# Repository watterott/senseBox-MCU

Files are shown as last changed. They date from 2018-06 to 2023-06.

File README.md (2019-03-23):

# senseBox MCU
senseBox MCU is a Microchip SAMD21 based open-source board for sensors.

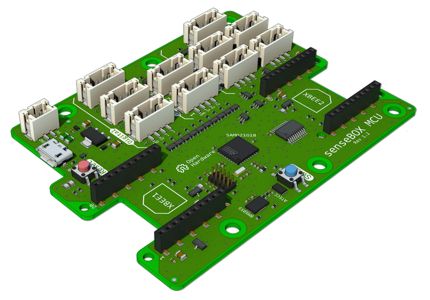
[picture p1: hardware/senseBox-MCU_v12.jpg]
senseBox MCU


* [Microchip ATSAMD21](https://www.microchip.com/wwwproducts/en/ATSAMD21G18) ARM Cortex-M0+ Microcontroller
* [Microchip ATECC608A](https://www.microchip.com/wwwproducts/en/ATECC608A) Crypto Authentication
* [Bosch BMX055](https://www.bosch-sensortec.com/bst/products/all_products/bmx055) Orientation Sensor (Accelerometer + Gyroscope + Magnetometer)
* USB CDC+MSC Bootloader (Arduino compatible)
* XBee compatible sockets (with UART and SPI)
* 5V tolerant IOs, UART, I2C (JST-PH connectors)
* MicroUSB connector for power and data
* Idle power consumption about 20mA (single 5V power supply)
* Open-Source
* **[Documentation on learn.watterott.com](https://learn.watterott.com)**

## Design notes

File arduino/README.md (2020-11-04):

# Board Support Package
Board Support Package for [Arduino IDE](https://www.arduino.cc/en/Main/Software).

## Installation

Add the following URL to the Arduino Boards Manager (*File->Preferences*):
```
https://github.com/watterott/senseBox-MCU/raw/master/package_sensebox_index.json
```
Then open the Arduino Boards Manager (*Tools->Boards->Boards Manager*) and install the 
**Arduino SAMD Boards** and **senseBox SAMD Boards**.

## Bootloader

The bootloader can be activated via the Arduino IDE or by doing two reset in 0.5s (double pressing the reset button next to the status LEDs).

When the bootloader is active then a new program can be loaded via the Arduino IDE and the serial port or via the mass storage device.
For the mass storage device just copy a new binary file (.bin) to the drive.

On Linux/Mac the dd command can be used to write the firmware: ```dd if=APP.BIN of=/media/SENSEBOX/APP.BIN conv=notrunc```

A binary file can be generated and exported in the Arduino IDE with *Sketch->Export compiled Binary* command.

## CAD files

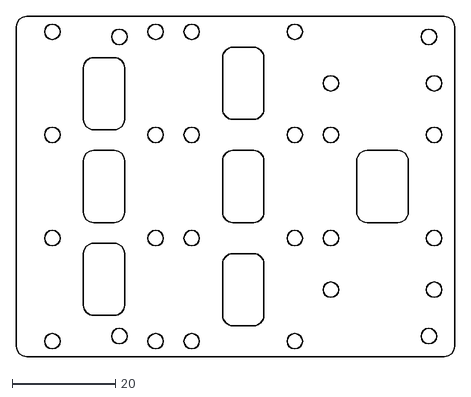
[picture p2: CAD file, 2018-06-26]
hardware/senseBox-Mount_v10.dxf
85.0 x 66.0

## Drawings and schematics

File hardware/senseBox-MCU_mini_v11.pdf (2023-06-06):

USB | SAMD21

A

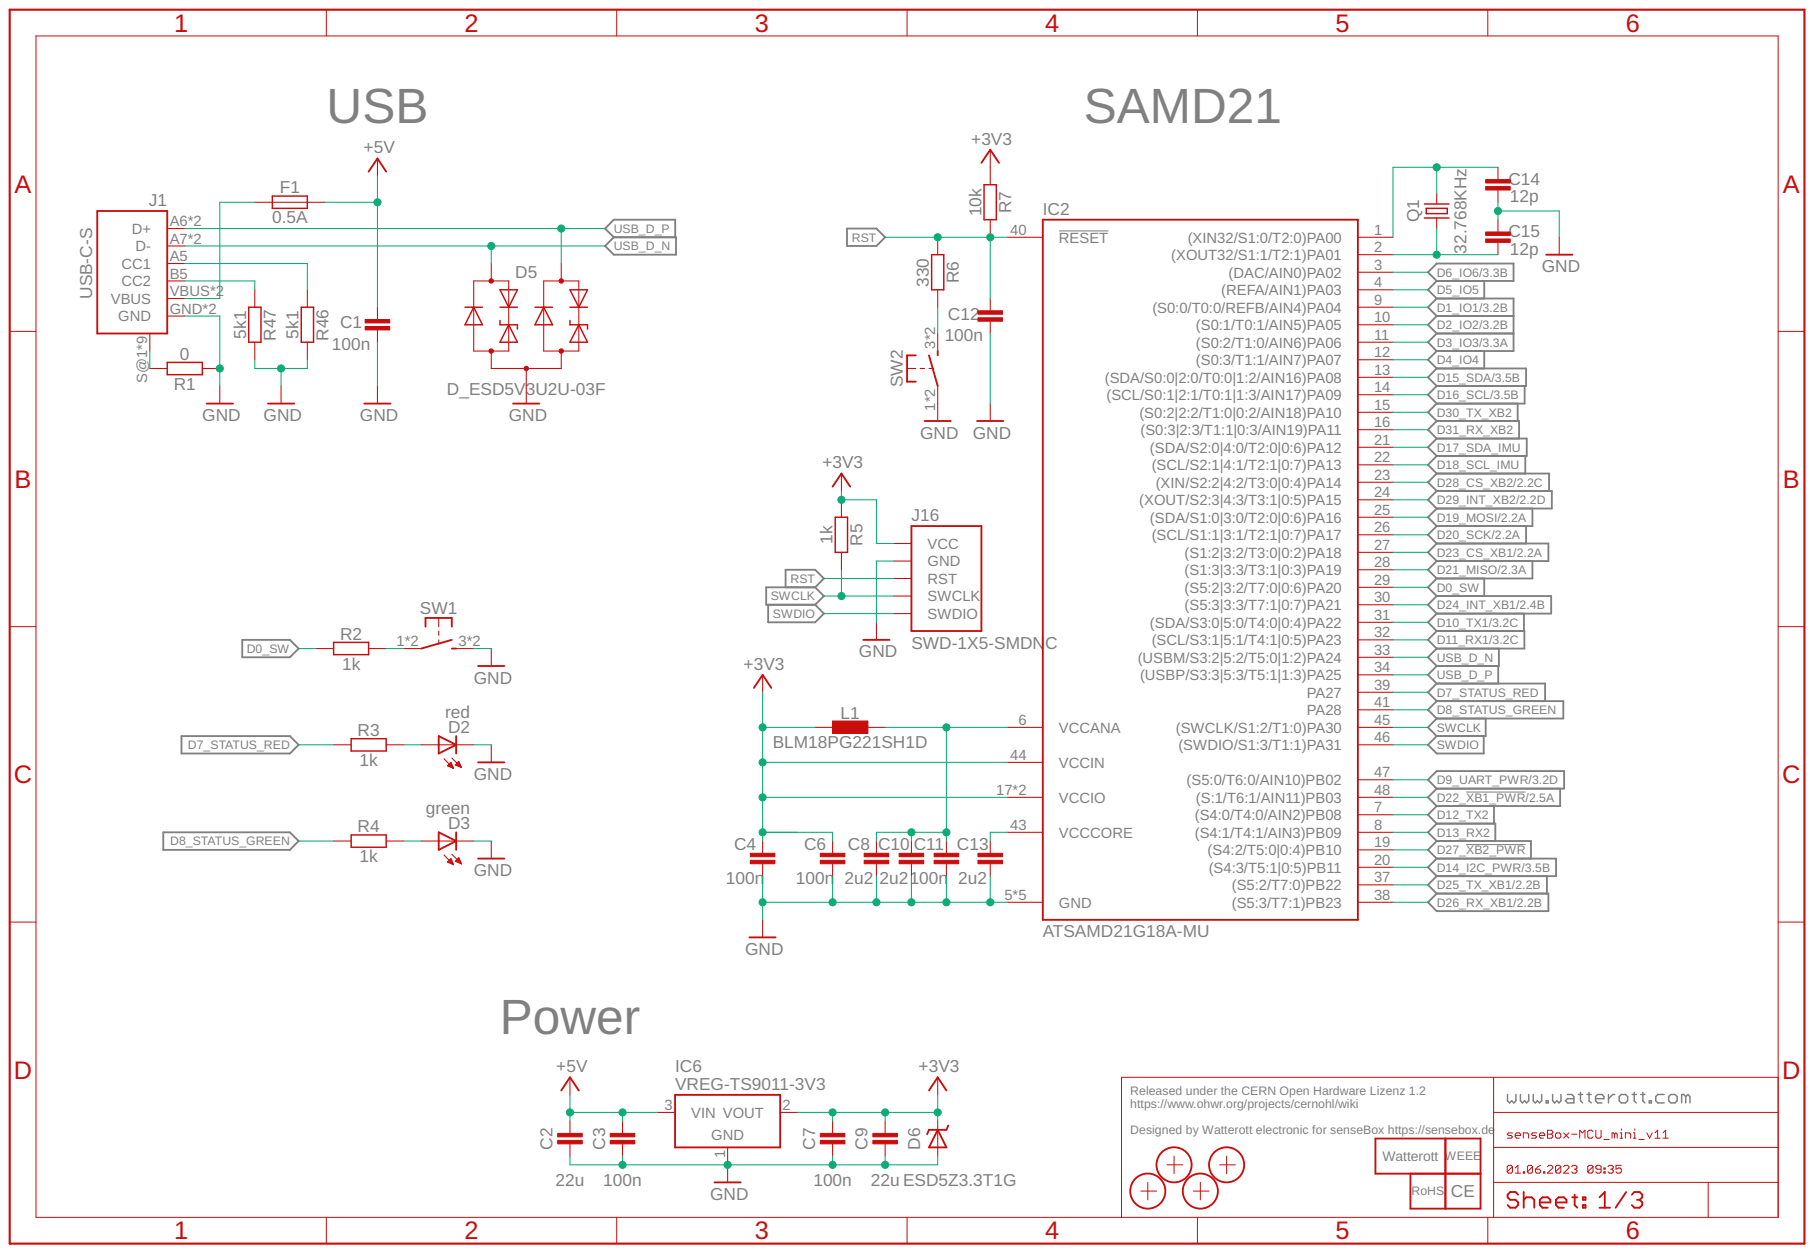
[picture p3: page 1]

https://www.ohwr.org/projects/cernohl/wiki Designed by Watterott electronic for senseBox https://sensebox.de

# XBee Socket

A

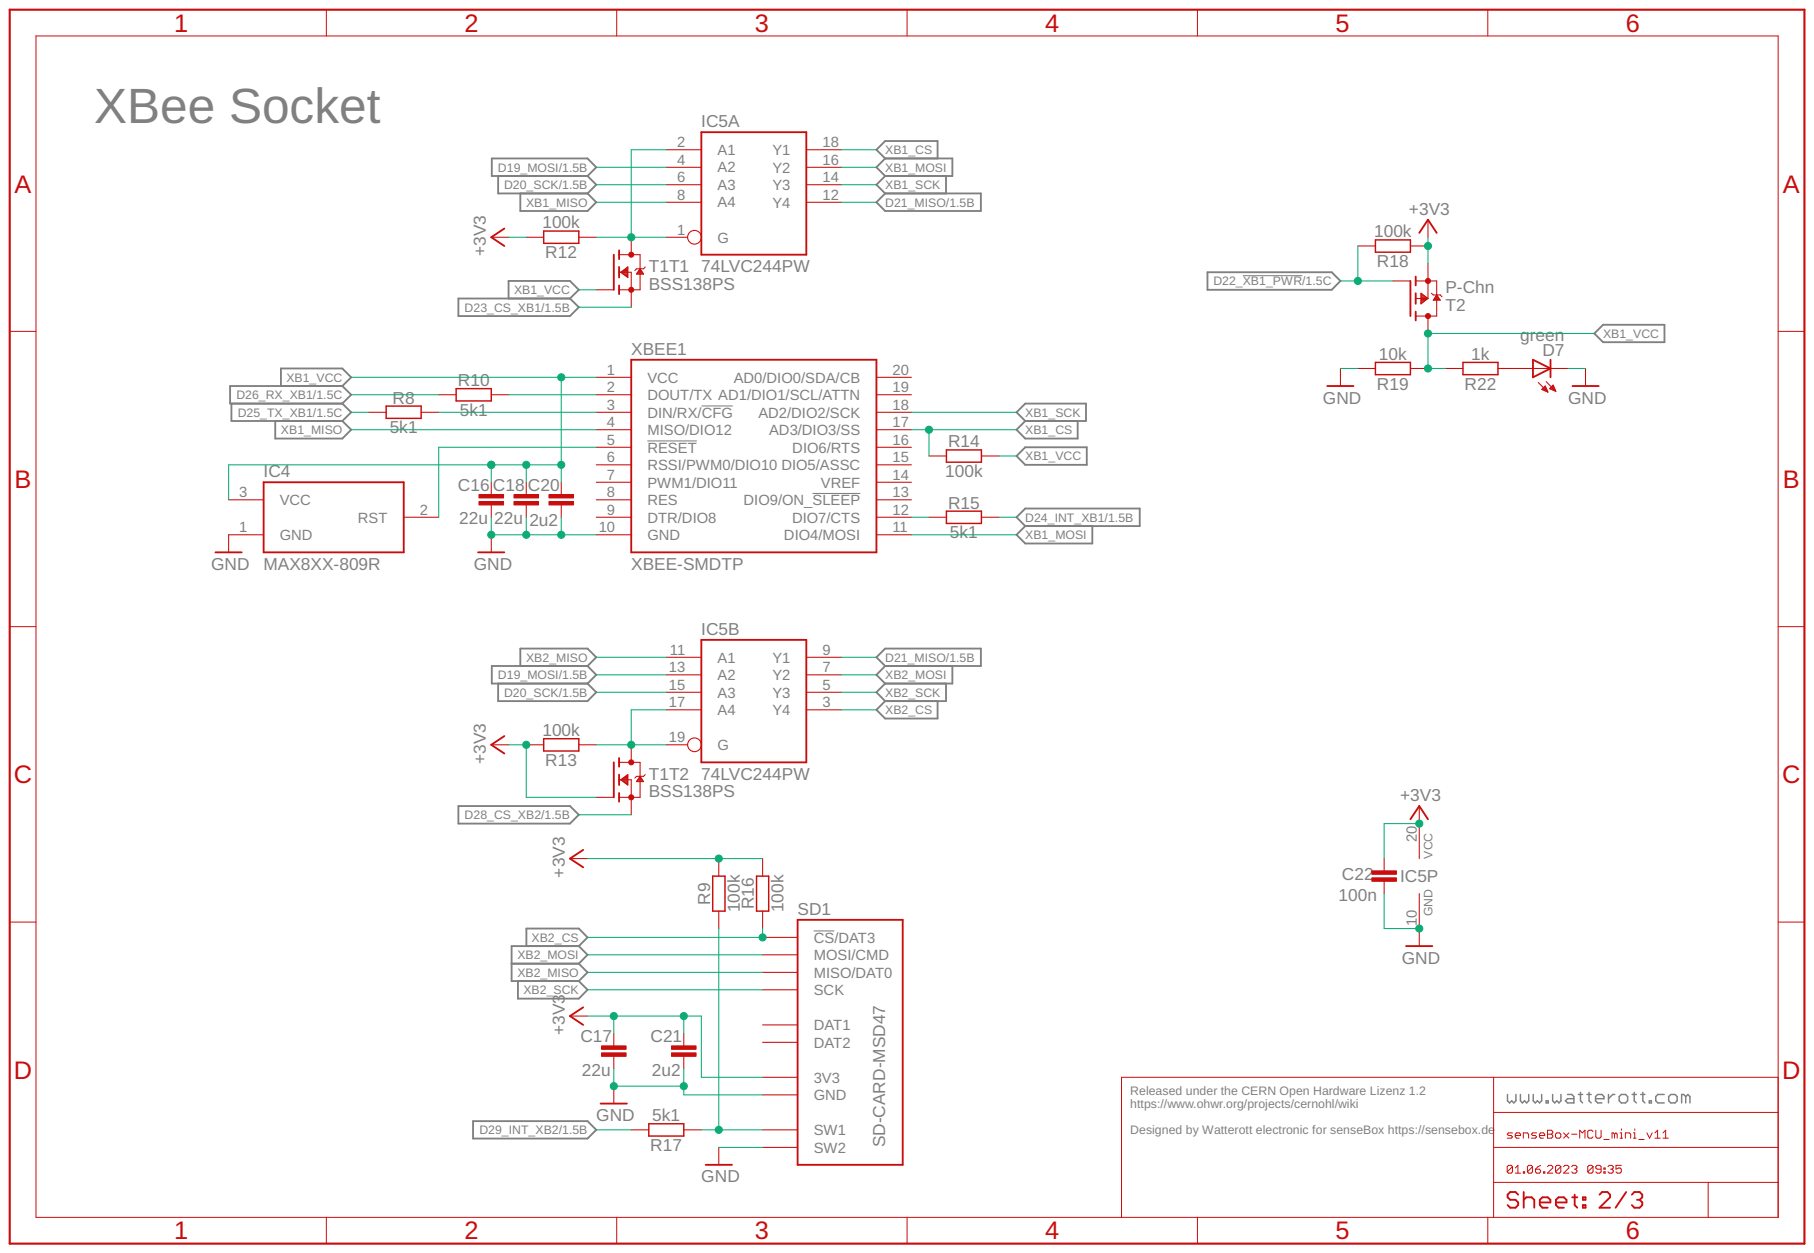
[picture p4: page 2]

Released under the CERN Open Hardware Lizenz 1.2
https://www.ohwr.org/projects/cernohl/wiki Designed by Watterott electronic for senseBox https://sensebox.de

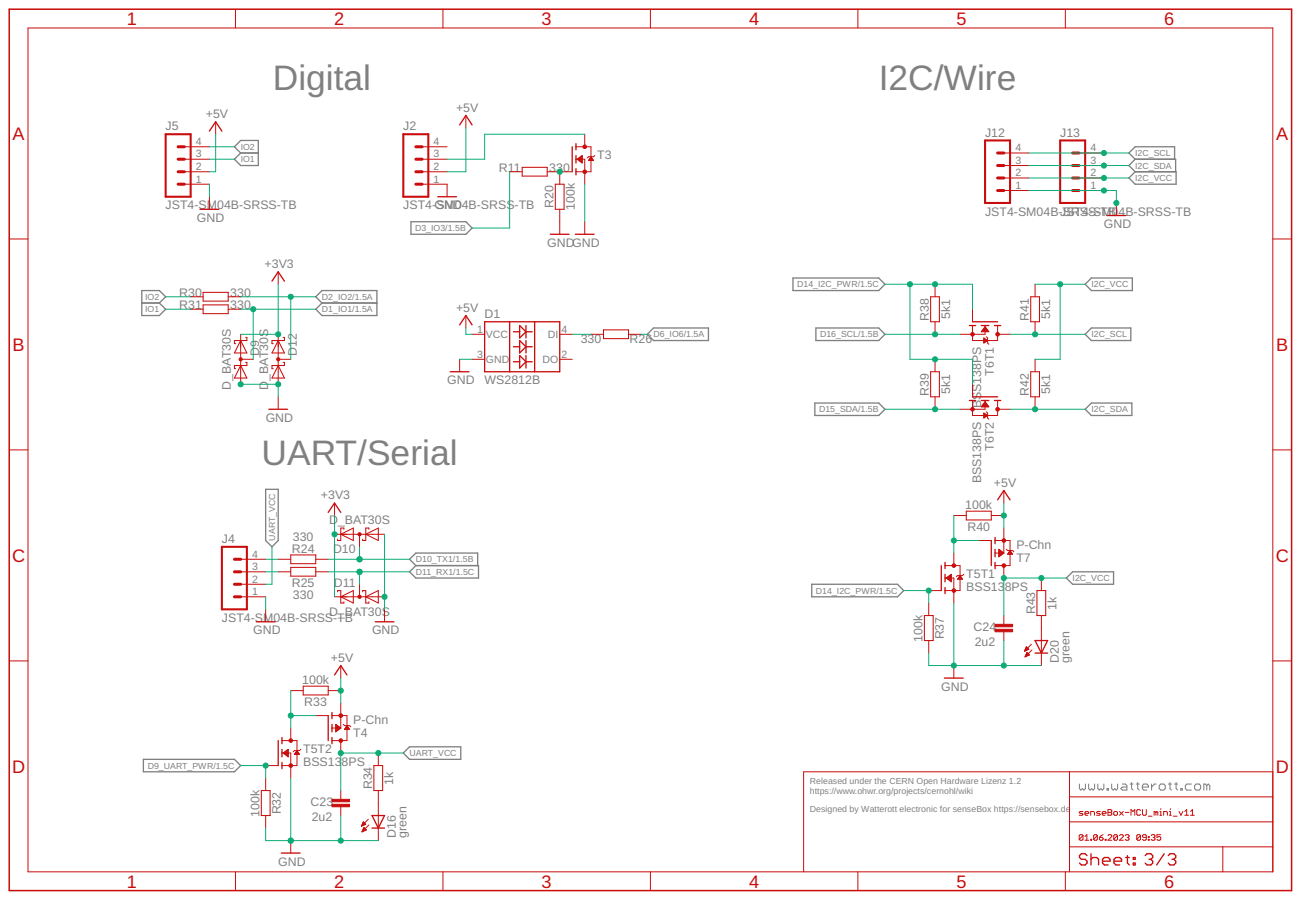
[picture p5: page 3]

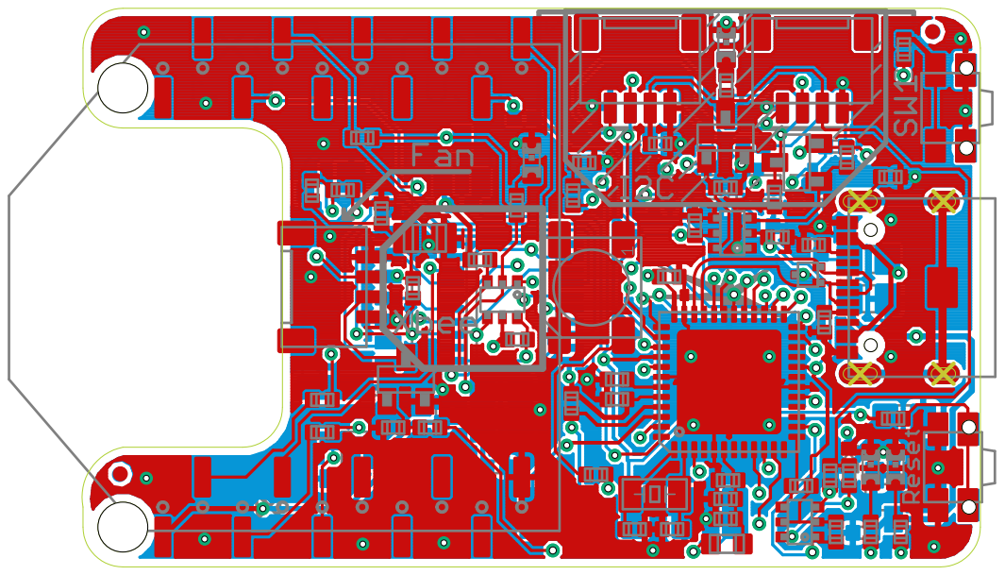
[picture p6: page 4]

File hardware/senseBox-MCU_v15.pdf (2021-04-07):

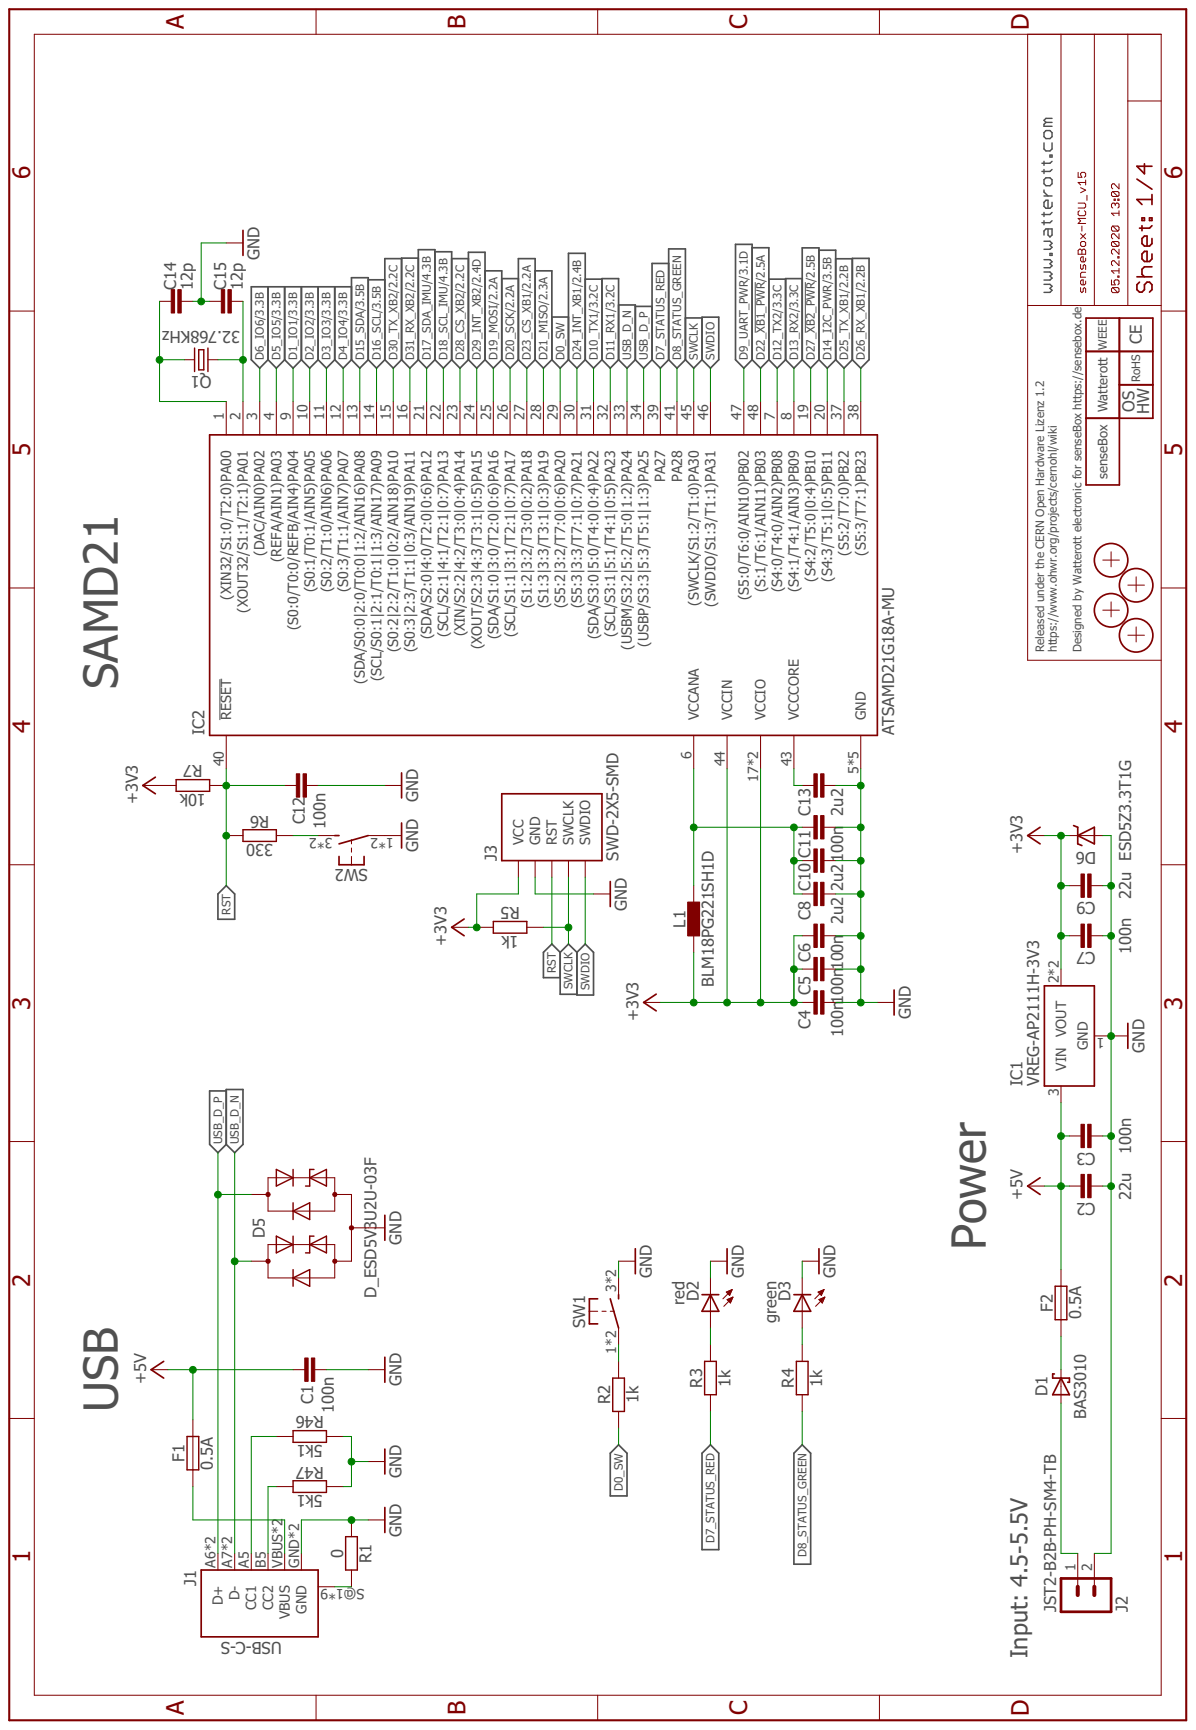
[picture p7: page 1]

Released under the CERN Open Hardware Lizenz 1.2 https://www.ohwr.org/projects/cernohl/wiki Designed by Watterott electronic for senseBox https://sensebox.de OS HW

F2 CE RoHS WEEE senseBox Watterott D1

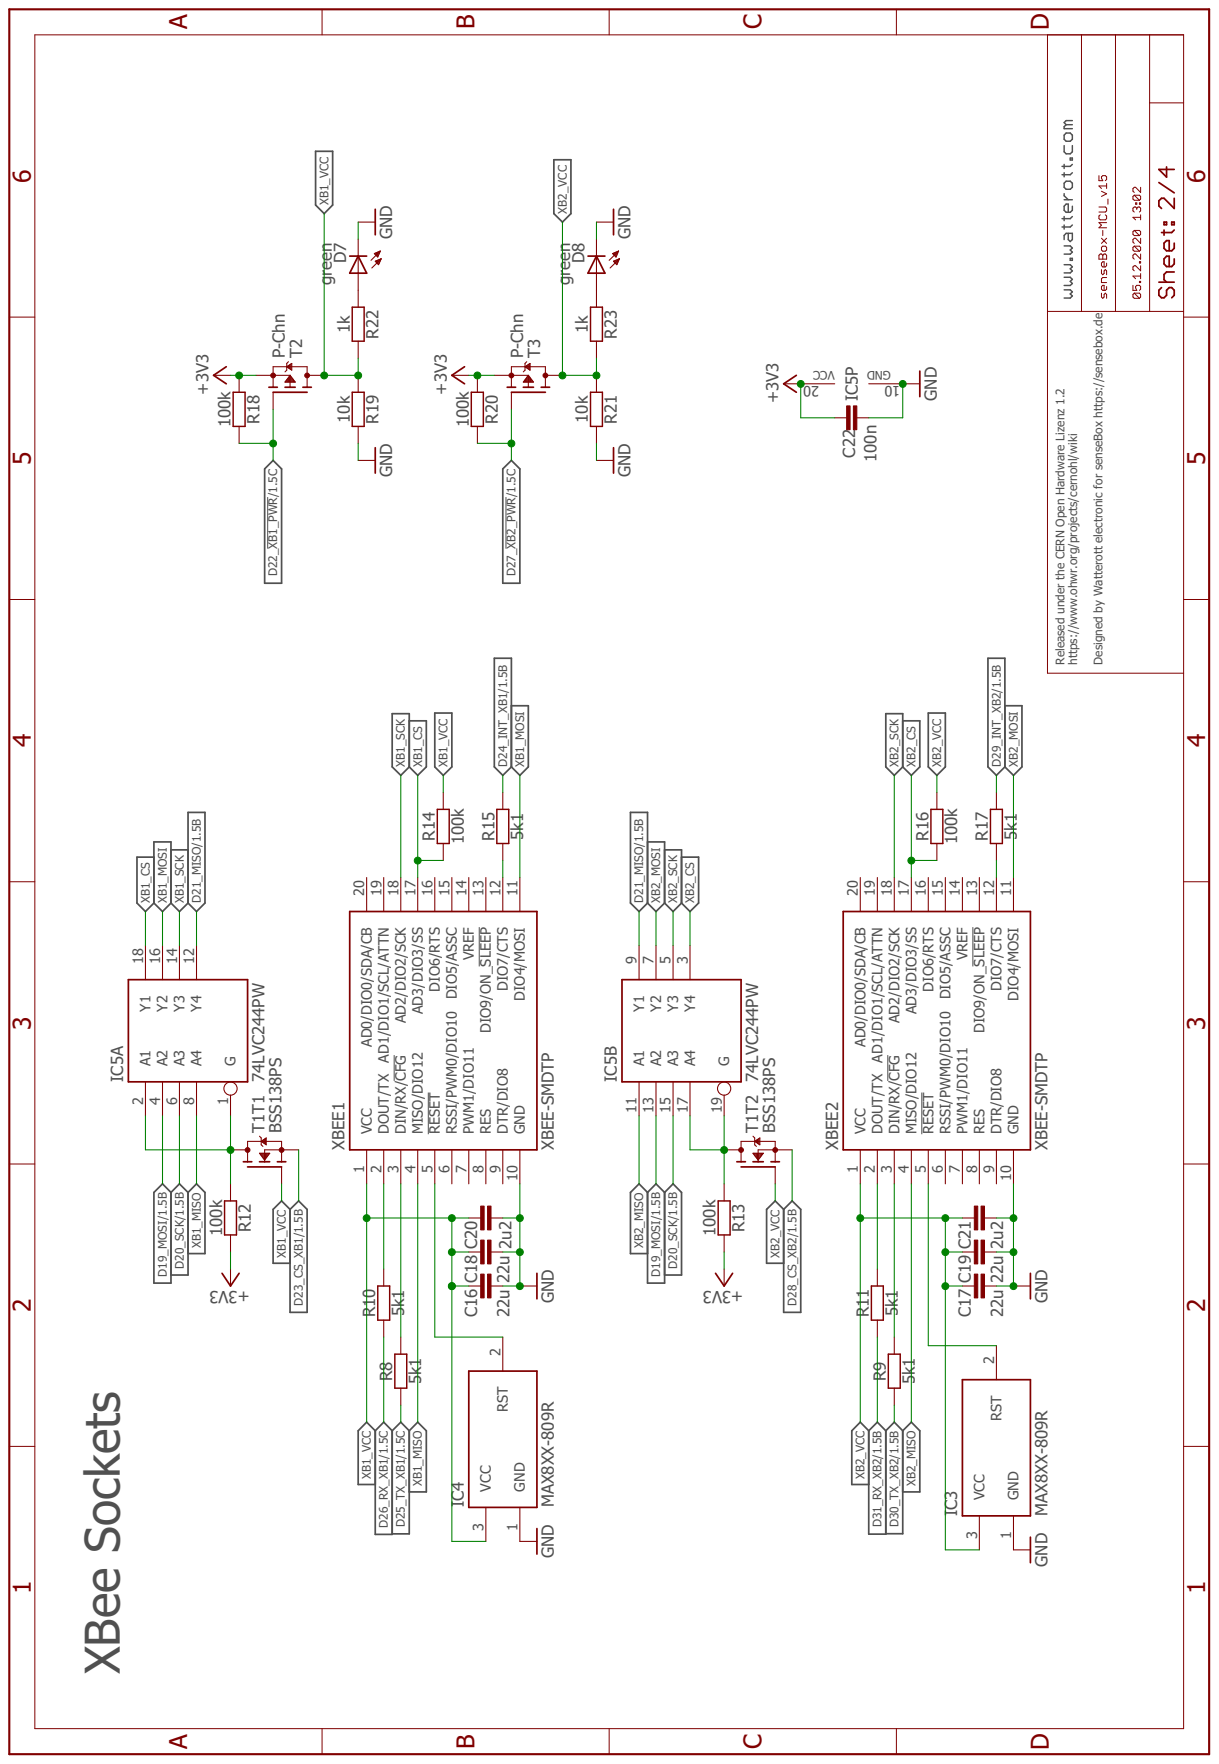
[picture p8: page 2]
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

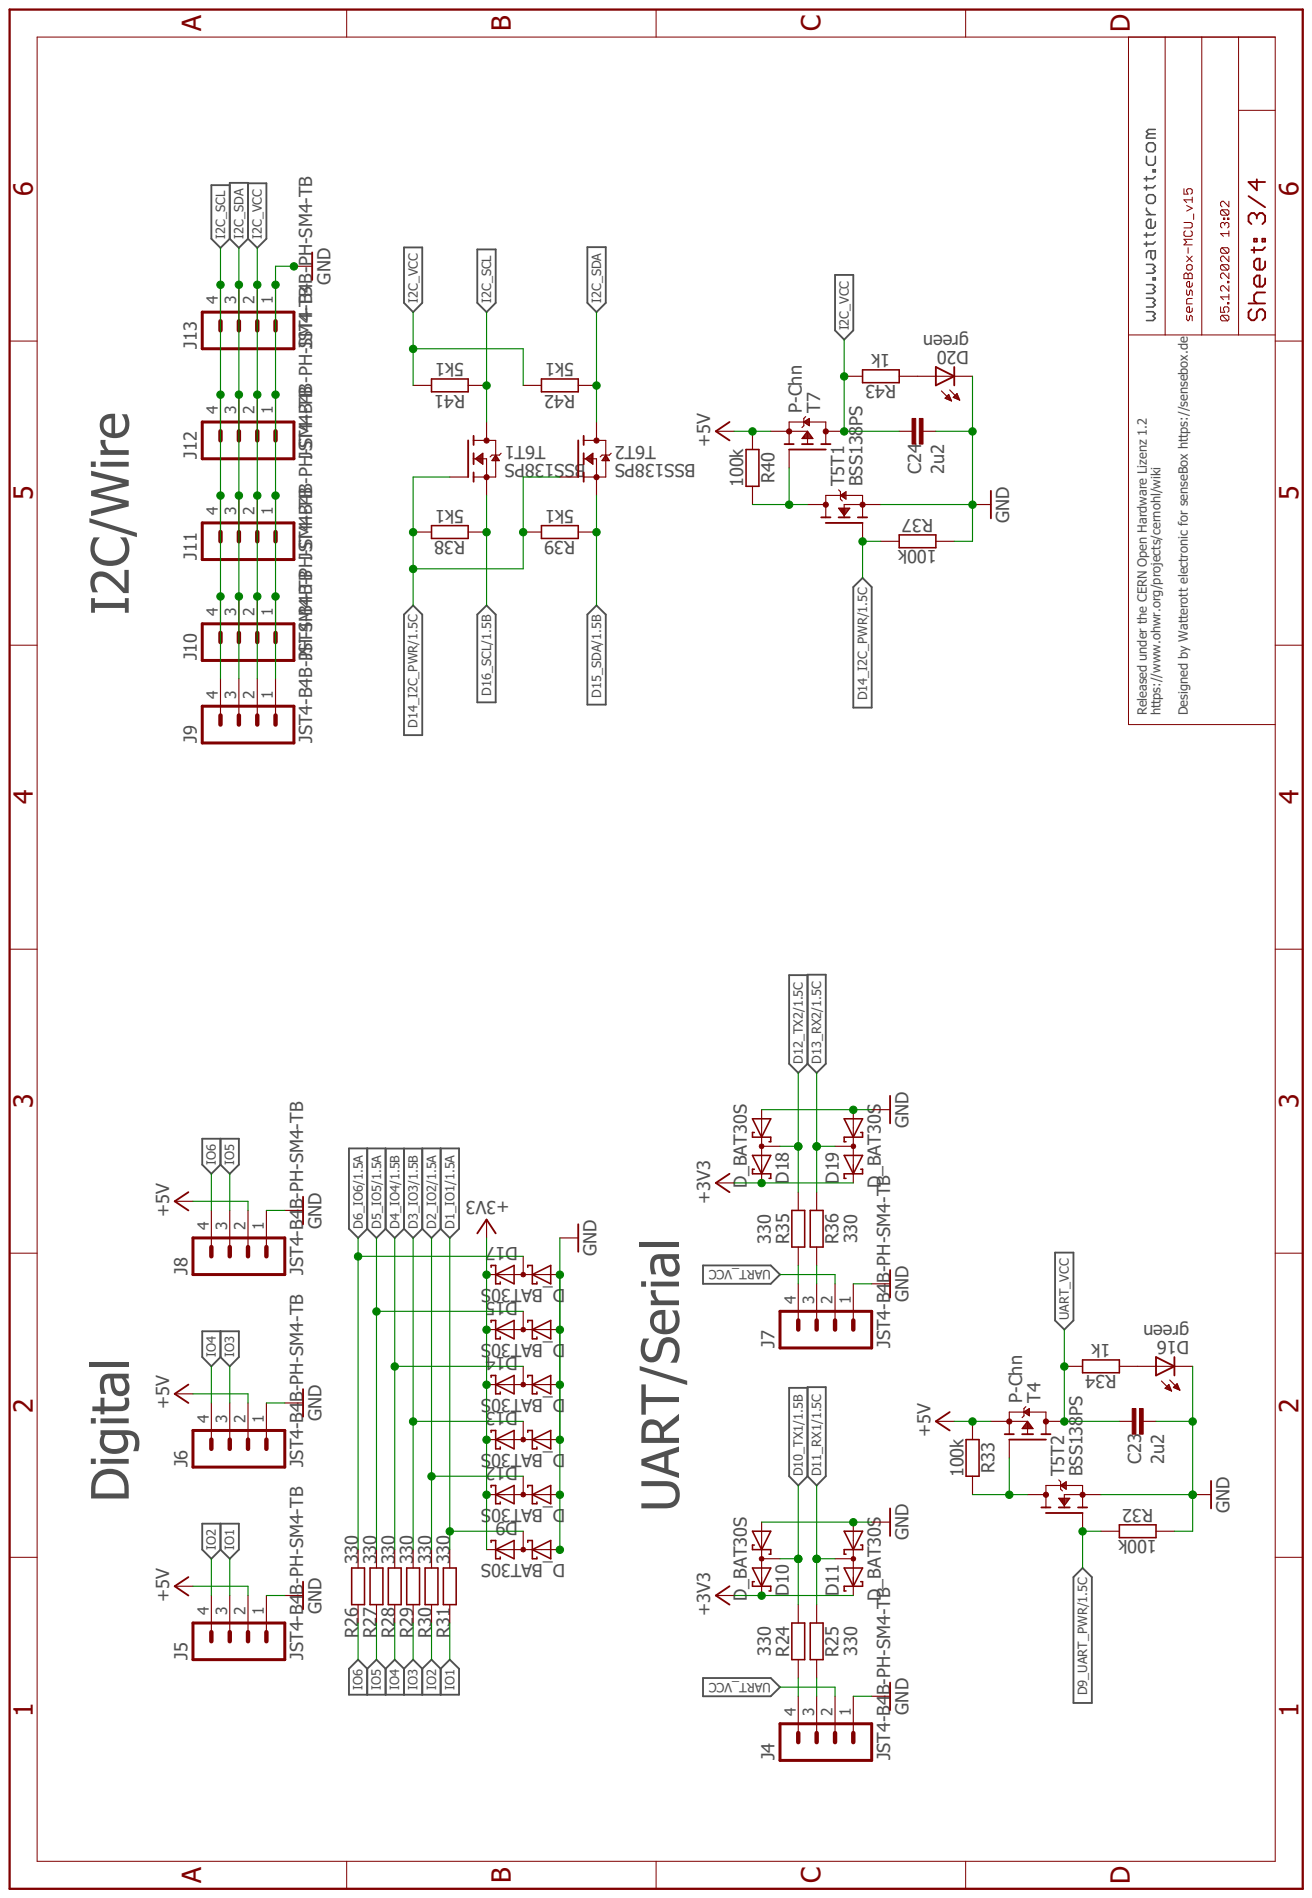
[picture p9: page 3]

JST4-B4B-PH-SM4-TB JST4-B4B-PH-SM4-TB

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

JST4-B4B-PH-SM4-TB

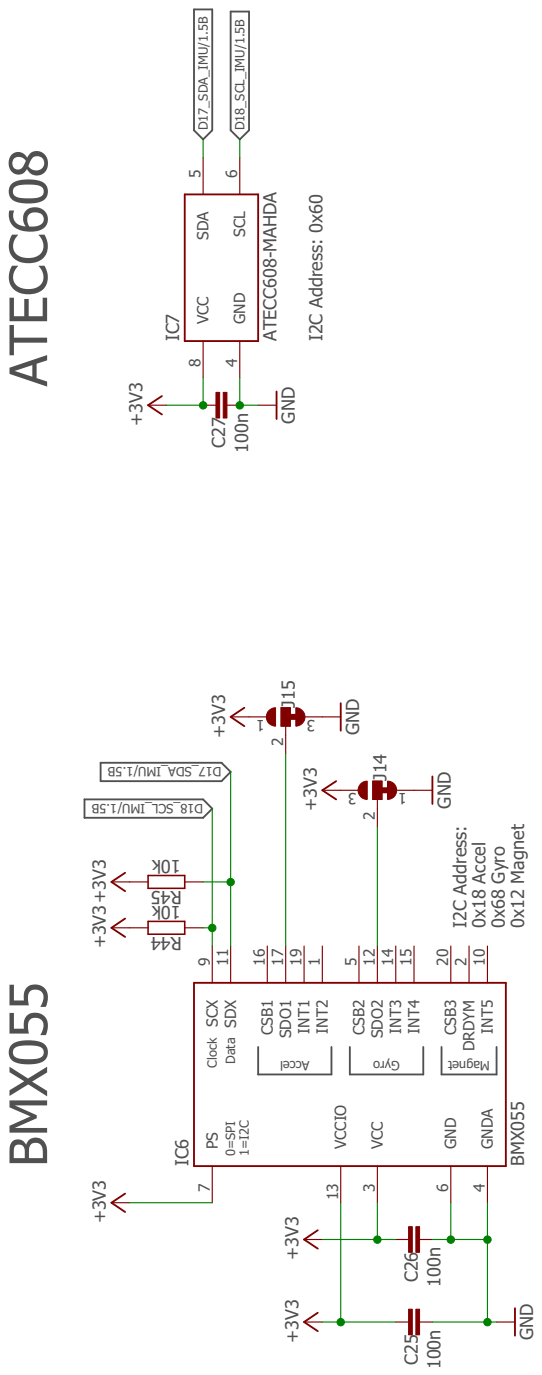
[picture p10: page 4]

I2C Address: 0x18 Accel 0x68 Gyro 0x12 Magnet I2C Address: 0x60 BMX055 ATECC608 l eccA or y G t enga M 0=SPI 1=I2C Clock Data BMX055 100n 100nGND k01 k01 +3V3 +3V3 +3V3+3V3 +3V3 +3V3 GND +3V3 100nGND +3V3 GND Released under the CERN Open Hardware Lizenz 1.2 https://www.ohwr.org/projects/cernohl/wiki Designed by Watterott electronic for senseBox https://sensebox.de PS 7 GND 6 CSB2 5 GNDA 4 VCC 3 DRDYM 2 INT2 1 SCX 9 INT5 10 SDX 11 SDO2 12 VCCIO 13 INT3 14 INT4 15 CSB1 16 SDO1 17 INT1 19 CSB3 20 IC6 C26 C25 44R 54R C27 1 3 2 J15 3 1 2 J14 IC7 ATECC608-MAHDA SCL 6 SDA 5 VCC 8 GND 4 B5. 1/ UMI _ADS_71D D17_SDA_IMU/1.5B B5. 1/ UMI _LCS_81D D18_SCL_IMU/1.5B ABCD 1 2 3 4 5 6 ABCD 1 2 3 4 5 6

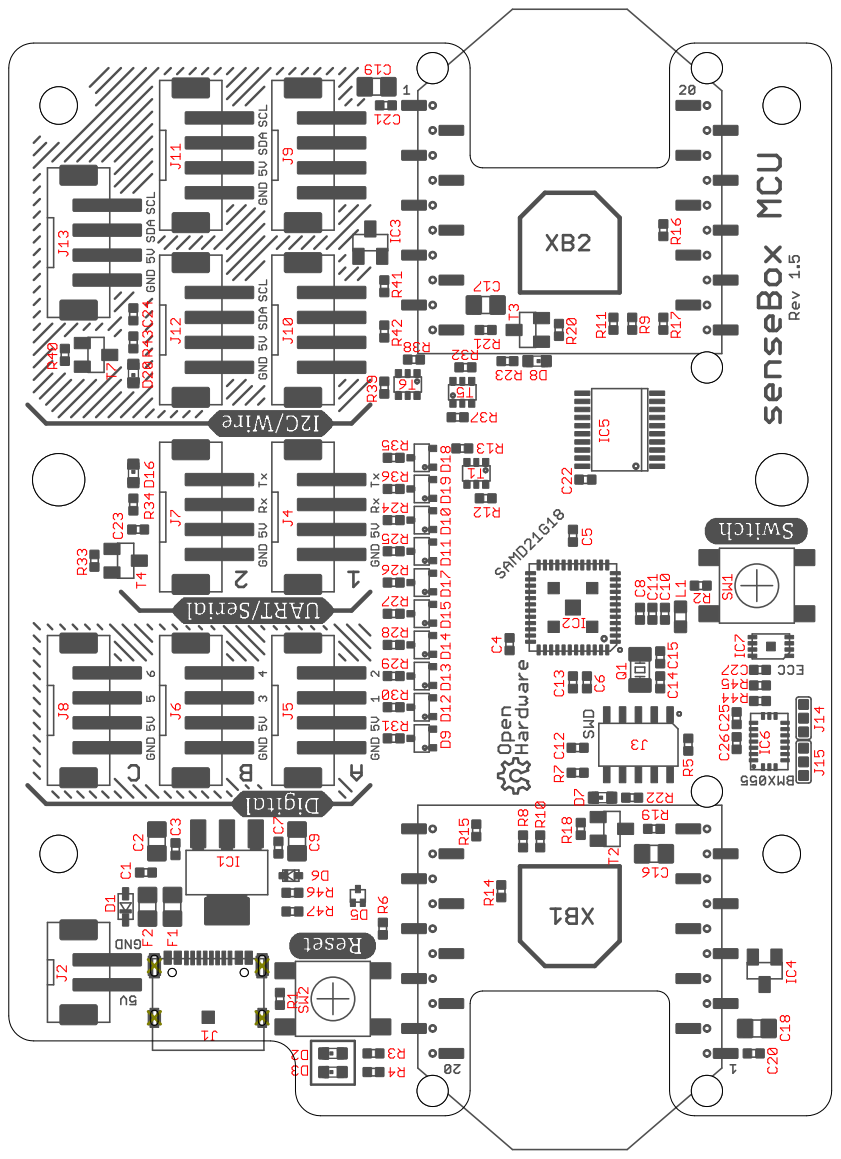
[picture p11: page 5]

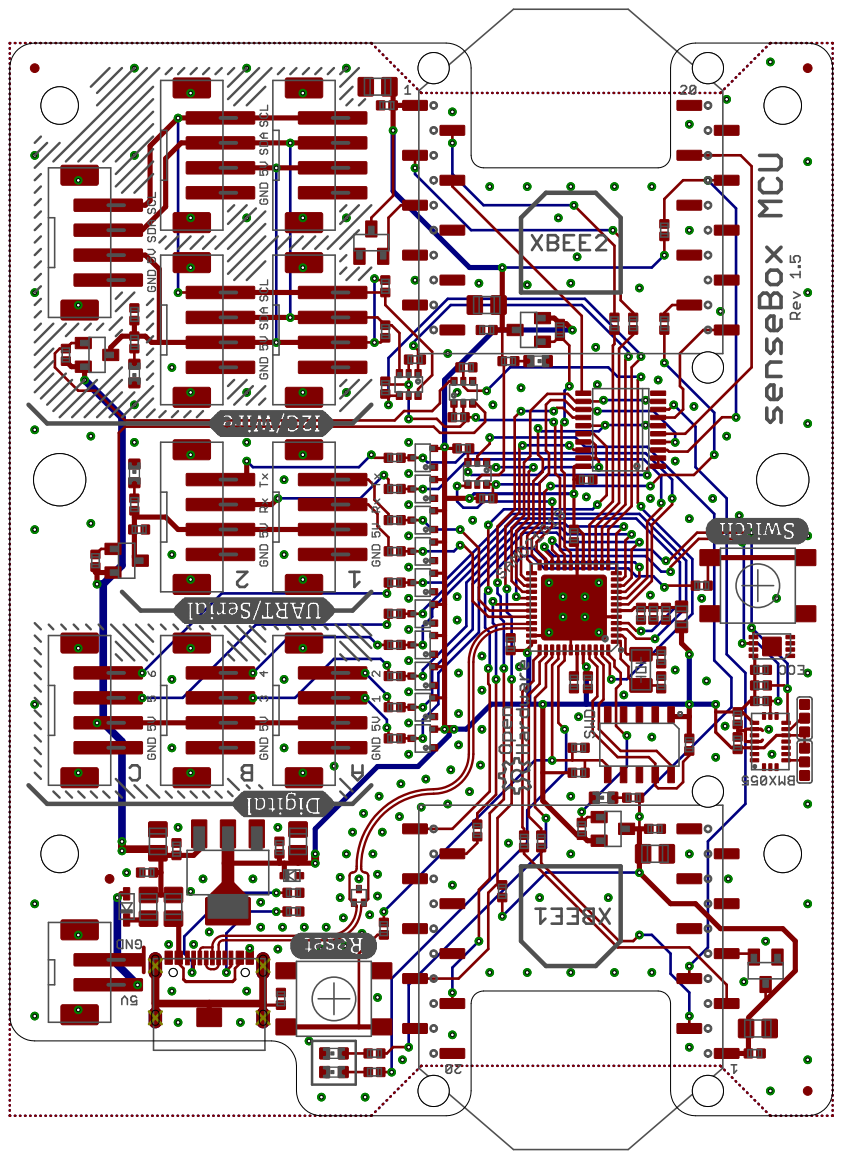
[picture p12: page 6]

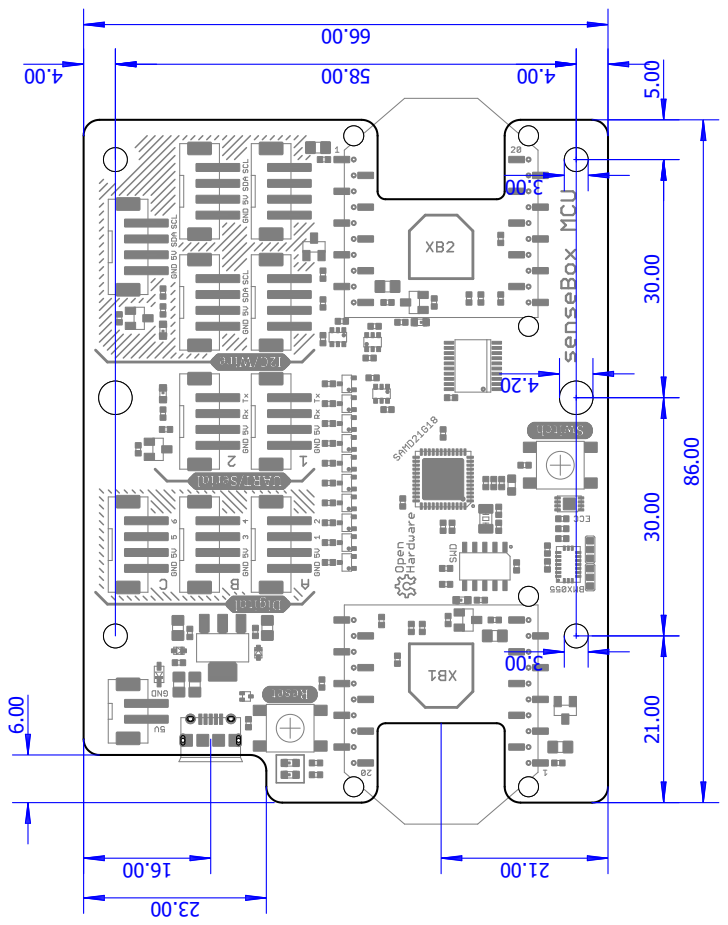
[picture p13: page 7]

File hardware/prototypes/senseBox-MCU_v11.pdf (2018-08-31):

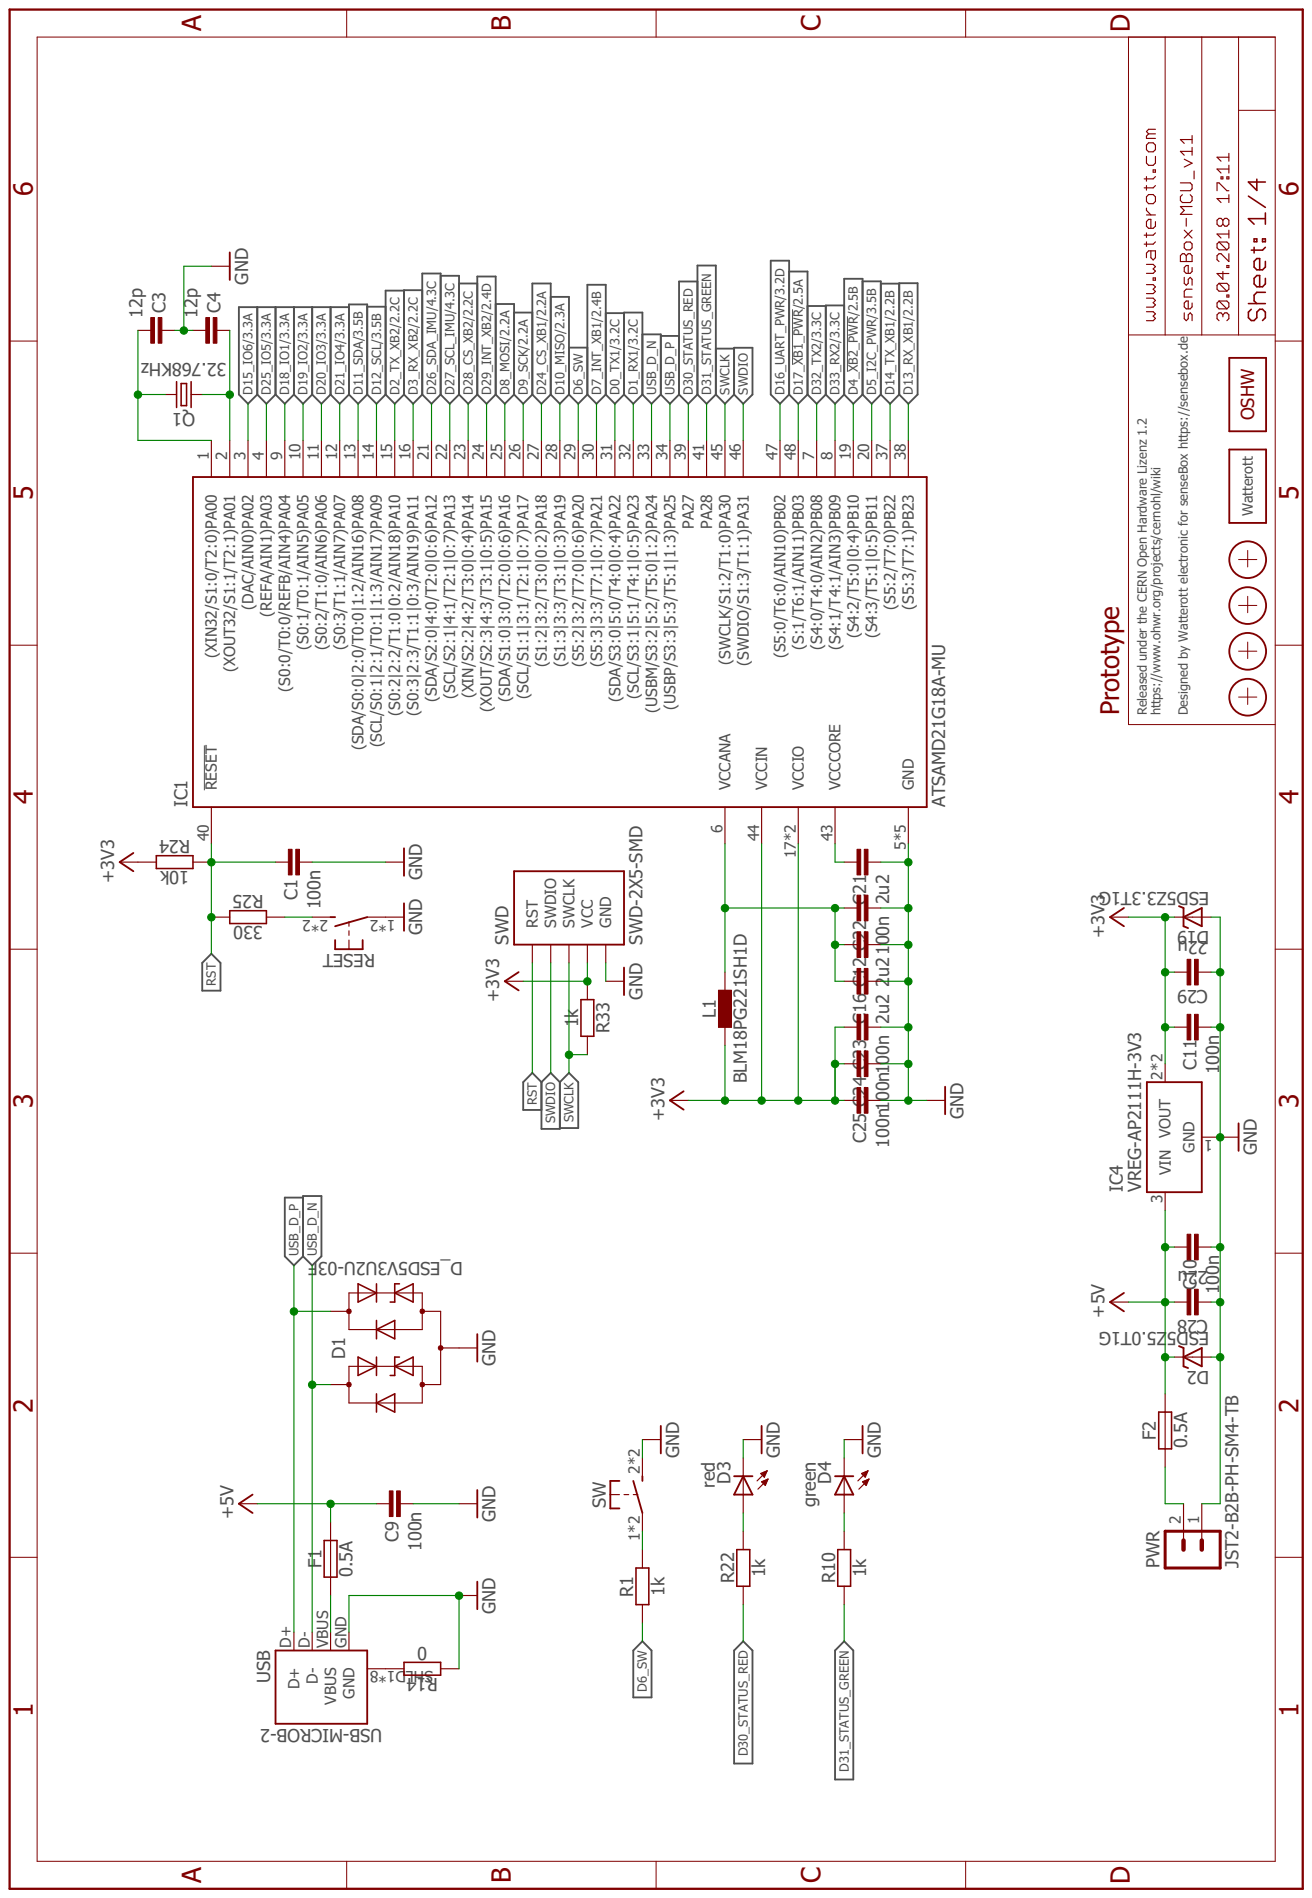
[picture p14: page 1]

ATSAMD21G18A-MU z HK867. 23 12p 12p GND +3V3 GND +3V3 GND 0 0.5A100+n 5V F30- U2U3V5DSE_D GNDG1T0. 5Z5DSE GND VREG-AP2111H-3V3 +5V GND 100n 100n red green 1k 2u2 100n 2u2 100n GND GNDk01 033 +3V3 1k 100n 100n 100n u22 u22 JST2-B2B-PH-SM4-TB 1k GND GND G1T3. 3Z5DSE +3V3 GND 1k BLM18PG221SH1D 2u2 0.5A GND Released under the CERN Open Hardware Lizenz 1.2 https://www.ohwr.org/projects/cernohl/wiki Designed by Watterott electronic for senseBox https://sensebox.de RESET 40 GND 5*5 IC1VCCANA 6 (XIN32/S1:0/T2:0)PA00 1 (XOUT32/S1:1/T2:1)PA01 2 (DAC/AIN0)PA02 3 (REFA/AIN1)PA03 4 (S0:0/T0:0/REFB/AIN4)PA04 9 (S0:1/T0:1/AIN5)PA05 10 (S0:2/T1:0/AIN6)PA06 11 (S0:3/T1:1/AIN7)PA07 12 (SDA/S0:0|2:0/T0:0|1:2/AIN16)PA08 13 (SCL/S0:1|2:1/T0:1|1:3/AIN17)PA09 14 (S0:2|2:2/T1:0|0:2/AIN18)PA10 15 (S0:3|2:3/T1:1|0:3/AIN19)PA11 16 (SDA/S2:0|4:0/T2:0|0:6)PA12 21 (SCL/S2:1|4:1/T2:1|0:7)PA13 22 (XIN/S2:2|4:2/T3:0|0:4)PA14 23 (XOUT/S2:3|4:3/T3:1|0:5)PA15 24 (SDA/S1:0|3:0/T2:0|0:6)PA16 25 (SCL/S1:1|3:1/T2:1|0:7)PA17 26 (S1:2|3:2/T3:0|0:2)PA18 27 (S1:3|3:3/T3:1|0:3)PA19 28 (S5:2|3:2/T7:0|0:6)PA20 29 (S5:3|3:3/T7:1|0:7)PA21 30 (SDA/S3:0|5:0/T4:0|0:4)PA22 31 (SCL/S3:1|5:1/T4:1|0:5)PA23 32 (USBM/S3:2|5:2/T5:0|1:2)PA24 33 (USBP/S3:3|5:3/T5:1|1:3)PA25 34 PA27 39 PA28 41 (SWCLK/S1:2/T1:0)PA30 45 (SWDIO/S1:3/T1:1)PA31 46 (S5:0/T6:0/AIN10)PB02 47 (S:1/T6:1/AIN11)PB03 48 (S4:0/T4:0/AIN2)PB08 7 (S4:1/T4:1/AIN3)PB09 8 (S4:2/T5:0|0:4)PB10 19 (S4:3/T5:1|0:5)PB11 20 (S5:2/T7:0)PB22 37 (S5:3/T7:1)PB23 38 VCCIO 17*2 VCCIN 44 VCCCORE 43 D+ D+ D- D- VBUS VBUS GND GND USB 2- BORCI M- BSU8*1DL HS TESER 2*2 2*1 SWD SWD-2X5-SMD SWCLK SWDIO VCC GND RST 1 Q C3C4 41R F1 C9 D1 2D IC4 GND VIN 3 V1 OUT 2*2 C10 C11 D3D4 R22 C21 C22 C16 C1 42R 52R R33 C23 C24 C25 82C 92C PWR 21 R10 91D SW 1*2 2*2 R1 L1 C12 F2 Watterott D8_MOSI/2.2A D9_SCK/2.2A D11_SDA/3.5B D12_SCL/3.5B SWCLK SWCLK SWDIO SWDIO RST RST D28_CS_XB2/2.2C D10_MISO/2.3A D21_IO4/3.3A USB_D_N USB_D_N USB_D_P USB_D_P D0_TX1/3.2C D32_TX2/3.3C D1_RX1/3.2C D33_RX2/3.3C D4_XB2_PWR/2.5B D24_CS_XB1/2.2A D3_RX_XB2/2.2C D2_TX_XB2/2.2C D13_RX_XB1/2.2B D14_TX_XB1/2.2B D7_INT_XB1/2.4B D29_INT_XB2/2.4D D26_SDA_IMU/4.3C D27_SCL_IMU/4.3C D15_IO6/3.3A D25_IO5/3.3A D18_IO1/3.3A D16_UART_PWR/3.2D D17_XB1_PWR/2.5A D30_STATUS_RED D30_STATUS_RED D31_STATUS_GREEN D31_STATUS_GREEN D5_I2C_PWR/3.5B D19_IO2/3.3A D20_IO3/3.3A D6_SW D6_SW Prototype ABCD 1 2 3 4 5 6 ABCD 1 2 3 4 5 6 OSHW

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


JST4-B4B-PH-SM4-TB JST4-B4B-PH-SM4-TB

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

JST4-B4B-PH-SM4-TB


I2C Address: 0x18 Accel 0x68 Gyro 0x12 Magnet I2C Address: 0x60 l eccA or y G t enga M 0=SPI 1=I2C Clock Data BMX055 100n 100nGND k01 k01 +3V3 +3V3 +3V3+3V3 +3V3 +3V3 GND +3V3 100nGND +3V3 GND Released under the CERN Open Hardware Lizenz 1.2 https://www.ohwr.org/projects/cernohl/wiki Designed by Watterott electronic for senseBox https://sensebox.de PS 7 GND 6 CSB2 5 GNDA 4 VCC 3 DRDYM 2 INT2 1 SCX 9 INT5 10 SDX 11 SDO2 12 VCCIO 13 INT3 14 INT4 15 CSB1 16 SDO1 17 INT1 19 CSB3 20 IC5 C26 C27 61R 43R IC2 ATECC608A-MAHDA SCL 6 SDA 5 VCC 8 GND 4 C8 1 3 2 J1 3 1 2 JB5. 1/ UMI _ADS_62D 2 D26_SDA_IMU/1.5B B5. 1/ UMI _LCS_72D D27_SCL_IMU/1.5B Prototype ABCD 1 2 3 4 5 6 ABCD 1 2 3 4 5 6


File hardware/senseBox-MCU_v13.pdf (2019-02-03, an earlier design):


Released under the CERN Open Hardware Lizenz 1.2 https://www.ohwr.org/projects/cernohl/wiki Designed by Watterott electronic for senseBox https://sensebox.de OS HW

F2 CE RoHS WEEE senseBox Watterott D1

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


JST4-B4B-PH-SM4-TB JST4-B4B-PH-SM4-TB

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

JST4-B4B-PH-SM4-TB


I2C Address: 0x18 Accel 0x68 Gyro 0x12 Magnet I2C Address: 0x60 BMX055 ATECC608 l eccA or y G t enga M 0=SPI 1=I2C Clock Data BMX055 100n 100nGND k01 k01 +3V3 +3V3 +3V3+3V3 +3V3 +3V3 GND +3V3 100nGND +3V3 GND Released under the CERN Open Hardware Lizenz 1.2 https://www.ohwr.org/projects/cernohl/wiki Designed by Watterott electronic for senseBox https://sensebox.de PS 7 GND 6 CSB2 5 GNDA 4 VCC 3 DRDYM 2 INT2 1 SCX 9 INT5 10 SDX 11 SDO2 12 VCCIO 13 INT3 14 INT4 15 CSB1 16 SDO1 17 INT1 19 CSB3 20 IC6 C26 C25 44R 54R C27 1 3 2 J15 3 1 2 J14 IC7 ATECC608A-MAHDA SCL 6 SDA 5 VCC 8 GND 4 B5. 1/ UMI _ADS_71D D17_SDA_IMU/1.5B B5. 1/ UMI _LCS_81D D18_SCL_IMU/1.5B ABCD 1 2 3 4 5 6 ABCD 1 2 3 4 5 6




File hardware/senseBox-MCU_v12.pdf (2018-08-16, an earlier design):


Released under the CERN Open Hardware Lizenz 1.2 https://www.ohwr.org/projects/cernohl/wiki Designed by Watterott electronic for senseBox https://sensebox.de OS HW

F2 CE RoHS WEEE senseBox Watterott senseBox

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


JST4-B4B-PH-SM4-TB JST4-B4B-PH-SM4-TB

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

JST4-B4B-PH-SM4-TB


I2C Address: 0x18 Accel 0x68 Gyro 0x12 Magnet I2C Address: 0x60 BMX055 ATECC608 l eccA or y G t enga M 0=SPI 1=I2C Clock Data BMX055 100n 100nGND k01 k01 +3V3 +3V3 +3V3+3V3 +3V3 +3V3 GND +3V3 100nGND +3V3 GND Released under the CERN Open Hardware Lizenz 1.2 https://www.ohwr.org/projects/cernohl/wiki Designed by Watterott electronic for senseBox https://sensebox.de PS 7 GND 6 CSB2 5 GNDA 4 VCC 3 DRDYM 2 INT2 1 SCX 9 INT5 10 SDX 11 SDO2 12 VCCIO 13 INT3 14 INT4 15 CSB1 16 SDO1 17 INT1 19 CSB3 20 IC6 C26 C25 44R 54R C27 1 3 2 J15 3 1 2 J14 IC7 ATECC608A-MAHDA SCL 6 SDA 5 VCC 8 GND 4 B5. 1/ UMI _ADS_71D D17_SDA_IMU/1.5B B5. 1/ UMI _LCS_81D D18_SCL_IMU/1.5B ABCD 1 2 3 4 5 6 ABCD 1 2 3 4 5 6




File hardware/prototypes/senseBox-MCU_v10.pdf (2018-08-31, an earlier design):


Released under the CERN Open Hardware Lizenz 1.2 https://www.ohwr.org/projects/cernohl/wiki Designed by Watterott electronic for senseBox https://sensebox.de

GND USB 2- BORCI M- BSU

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


JST4-B4B-PH-SM4-TB JST4-B4B-PH-SM4-TB JST4-B4B-PH-SM4-TB JST4-B4B-PH-SM4-TB JST4-B4B-PH-SM4-TB JST4-B4B-PH-SM4-TB JST4-B4B-PH-SM4-TB JST4-B4B-PH-SM4-TB 74LVC244PW SP831SSB 7k4 7k4 7k4 7k4 SP831SSB +3V3 +3V3 Released under the CERN Open Hardware Lizenz 1.2 https://www.ohwr.org/projects/cernohl/wiki Designed by Watterott electronic for senseBox https://sensebox.de J1 4321 J2 4321 J3 4321 J4 4321 J5 4321 J6 4321 J7 4321 J8 4321 IC3BG 19 A1 11 A2 13 A3 15 A4 17 Y4 3 Y3 5 Y2 7 Y1 9 1T5T 3R4R 5R7R 2T5T GND/4.1C GND/4.1C I2C_VCC/1.6C I2C_VCC/1.6C I2C_VCC/1.6C I2C_SDA I2C_SDA I2C_SCL I2C_SCL UART_VCC/1.6D UART_TX2 UART_TX2 UART_RX2 UART_RX2 MCU_SDA/1.4A MCU_SCL/1.4A UART_CS/1.5UCART_RX1 UART_RXU1ART_TX1 UART_TX1 MCU_TX1/1.4B MCU_TX2/1.4C MCU_RX1/1.4B MCU_RX2/1.4C Prototype ABCD 1 2 3 4 5 6 ABCD 1 2 3 4 5 6


100k GND 100n 2u2 100k 3V3 + 74LVC244PW 100n 100n GND 7k4 7k4 +3V3 +3V3 +3V3+3V33V3 + k001 k001 k001 k001 +3V3 +3V3 GND GND +3V3 100nGND Released under the CERN Open Hardware Lizenz 1.2 https://www.ohwr.org/projects/cernohl/wiki Designed by Watterott electronic for senseBox https://sensebox.de DAT2 CSMOSI 3V3 SCK GND MISO DAT1 SW1 SW2 SD 05DS M- DRAC- DS R1 C5 C6 R15 IC5AG 1 A1 2 A2 4 A3 6 A4 8 Y4 12 Y3 14 Y2 16 Y1 18 PS 7 GND 6 CSB2 5 GNDA 4 VCC 3 DRDYM 2 INT2 1 SCX 9 INT5 10 SDX 11 SDO2 12 VCCIO 13 INT3 14 INT4 15 CSB1 16 SDO1 17 INT1 19 CSB3 20 C26 C27 61R 43R 53R 63R 73R 83R IC2 ATECC508A-MAHDA-S SCL 6 SDA 5 VCC 8 GND 4 C8 MCU_MOSI/2.3C MCU_SCK/2.3C SD_CS SD_CS SD_MOSI SD_MOSI SD_MISO SD_MISO SD_SCK SD_SCK MCU_CS_SD/1.4B MCU_MISO/2.4C SD_VCC/1.6B IMU_SDA/1.4B IMU_SDA/1.4B IMU_SCL/1.4B IMU_SCL/1.4BSDO2 SDO2 SDO1 SDO1 Prototype ABCD 1 2 3 4 5 6 ABCD 1 2 3 4 5 6


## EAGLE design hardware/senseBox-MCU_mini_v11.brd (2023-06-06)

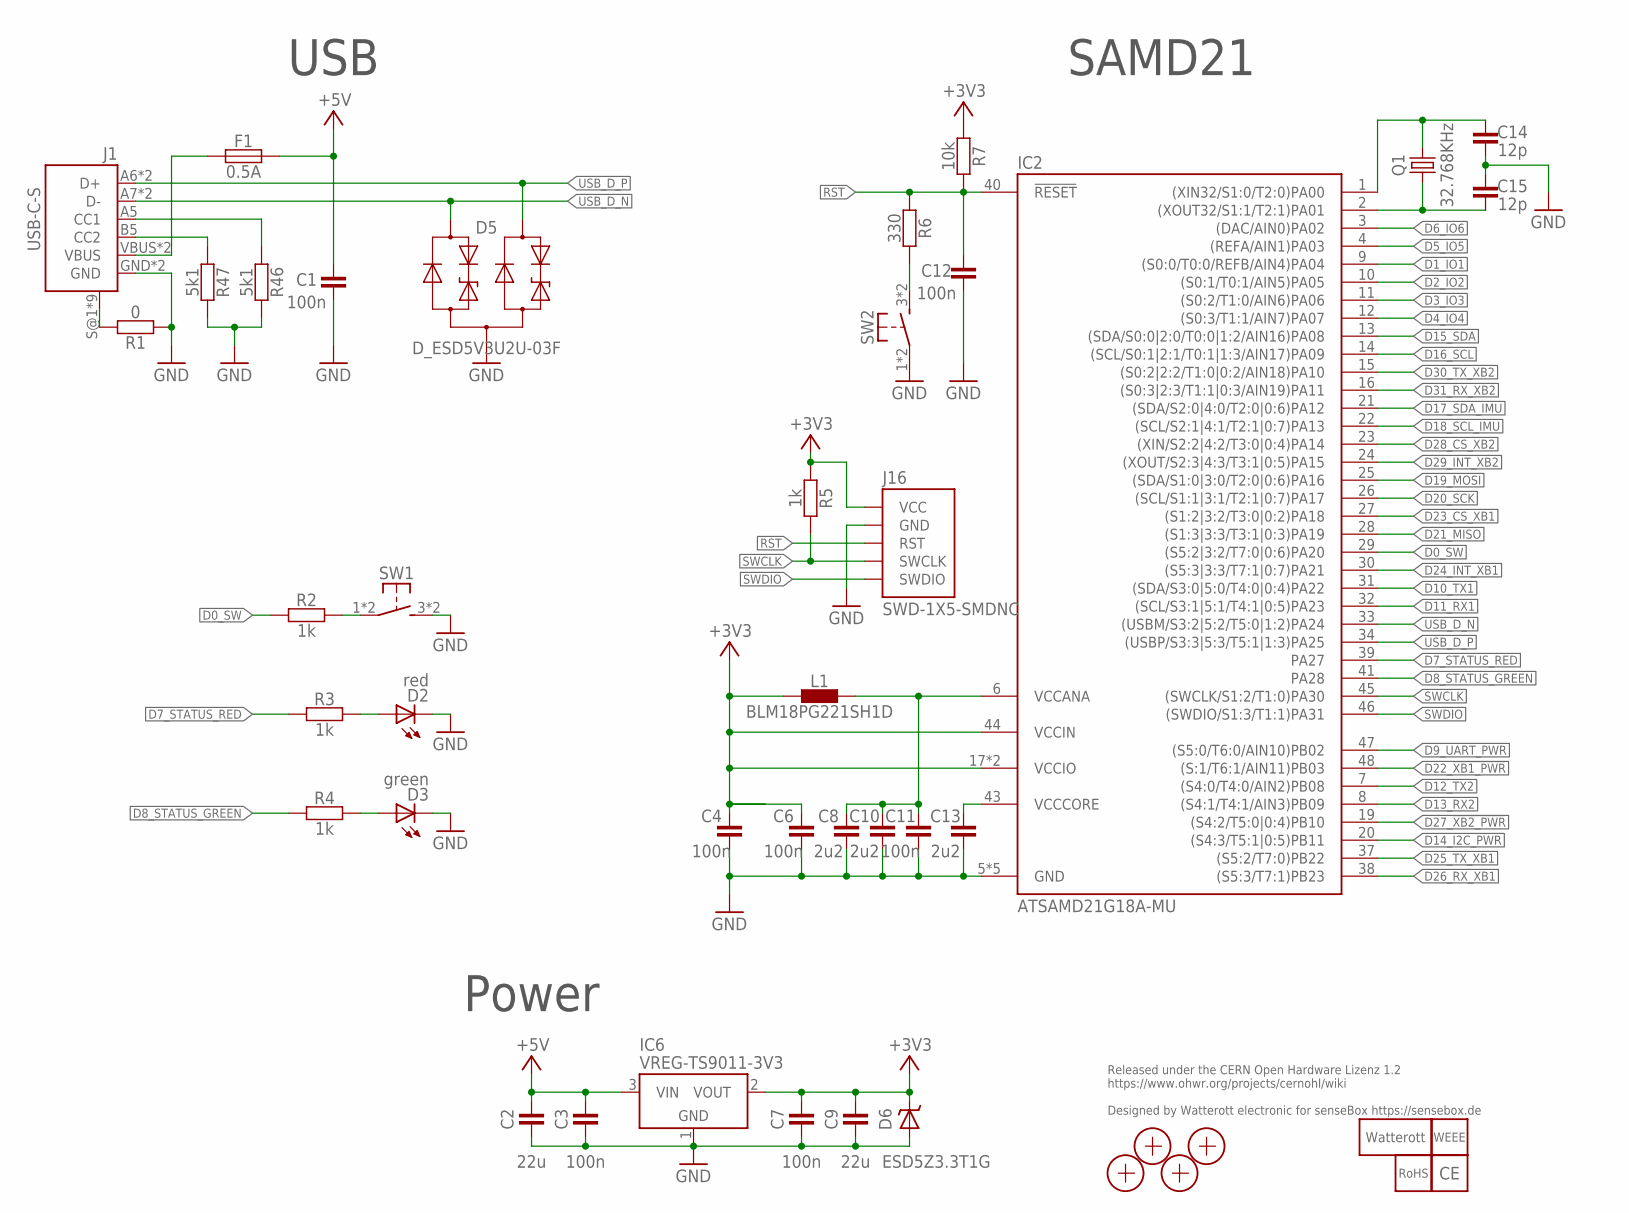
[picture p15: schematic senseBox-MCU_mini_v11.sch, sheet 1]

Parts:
C1, C3, C4, C6, C7, C11, C12: 100n; C0402
C2, C9: 22u; C0805
C8, C10, C13: 2u2; C0402
C14, C15: 12p; C0402
D2: red; C0603
D3: green; C0603
D5: D_ESD5V3U2U-03F; SOT723
D6: ESD5Z3.3T1G; SOD523
F1: 0.5A; C0805
IC2: ATSAMD21G18A-MU; QFN48-PAD
IC6: VREG-TS9011-3V3; SOT23
J1: USB-C-S
J16: SWD-1X5-SMDNC; SWD-1X5_SMDNC
L1: BLM18PG221SH1D; C0603
LOGO4: LOGO_SPARK-4; SPARK_4MM
LOGO5: LOGO_ROHS-2; ROHS_2MM
LOGO6: LOGO_WEEE-4; WEEE_4MM
LOGO7: LOGO_CE-2; CE_2MM
Q1: 32.768KHz; CRYSTAL_ZM315
R1: 0; C0402
R2, R3, R4, R5: 1k; C0402
R6: 330; C0402
R7: 10k; C0402
R46, R47: 5k1; C0402
SW1: PTS645SH50SMTR92-Grey; PTS840P
SW2: PTS645SK50SMTR92-Red; PTS840P
X1, X2, X3, X4: PASSER-07; PASSER_07MM

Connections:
+3V3: C4.2, C6.2, C7.2, C9.2, D6.C, IC2.17 (VCCIO), IC2.36 (VCCIO), IC2.44 (VCCIN), IC6.2 (VOUT), J16.1-VCC (VCC), L1.1, R5.1, R7.1; also elsewhere on the board
+5V: C1.2, C2.2, C3.2, F1.2, IC6.3 (VIN); also elsewhere on the board
CC1: J1.A5 (CC1), R46.1
CC2: J1.B5 (CC2), R47.1
D0_SW: IC2.29 ((S5:2|3:2/T7:0|0:6)PA20), R2.1
D1_IO1: IC2.9 ((S0:0/T0:0/REFB/AIN4)PA04); also elsewhere on the board
D2_IO2: IC2.10 ((S0:1/T0:1/AIN5)PA05); also elsewhere on the board
D3_IO3: IC2.11 ((S0:2/T1:0/AIN6)PA06); also elsewhere on the board
D4_IO4: IC2.12 ((S0:3/T1:1/AIN7)PA07)
D5_IO5: IC2.4 ((REFA/AIN1)PA03)
D6_IO6: IC2.3 ((DAC/AIN0)PA02); also elsewhere on the board
D7_STATUS_RED: IC2.39 (PA27), R3.1
D8_STATUS_GREEN: IC2.41 (PA28), R4.1
D9_UART_PWR: IC2.47 ((S5:0/T6:0/AIN10)PB02); also elsewhere on the board
D10_TX1: IC2.31 ((SDA/S3:0|5:0/T4:0|0:4)PA22); also elsewhere on the board
D11_RX1: IC2.32 ((SCL/S3:1|5:1/T4:1|0:5)PA23); also elsewhere on the board
D12_TX2: IC2.7 ((S4:0/T4:0/AIN2)PB08)
D13_RX2: IC2.8 ((S4:1/T4:1/AIN3)PB09)
D14_I2C_PWR: IC2.20 ((S4:3/T5:1|0:5)PB11); also elsewhere on the board
D15_SDA: IC2.13 ((SDA/S0:0|2:0/T0:0|1:2/AIN16)PA08); also elsewhere on the board
D16_SCL: IC2.14 ((SCL/S0:1|2:1/T0:1|1:3/AIN17)PA09); also elsewhere on the board
D17_SDA_IMU: IC2.21 ((SDA/S2:0|4:0/T2:0|0:6)PA12)
D18_SCL_IMU: IC2.22 ((SCL/S2:1|4:1/T2:1|0:7)PA13)
D19_MOSI: IC2.25 ((SDA/S1:0|3:0/T2:0|0:6)PA16); also elsewhere on the board
D20_SCK: IC2.26 ((SCL/S1:1|3:1/T2:1|0:7)PA17); also elsewhere on the board
D21_MISO: IC2.28 ((S1:3|3:3/T3:1|0:3)PA19); also elsewhere on the board
D22_!XB1_PWR: IC2.48 ((S:1/T6:1/AIN11)PB03); also elsewhere on the board
D23_CS_XB1: IC2.27 ((S1:2|3:2/T3:0|0:2)PA18); also elsewhere on the board
D24_INT_XB1: IC2.30 ((S5:3|3:3/T7:1|0:7)PA21); also elsewhere on the board
D25_TX_XB1: IC2.37 ((S5:2/T7:0)PB22); also elsewhere on the board
D26_RX_XB1: IC2.38 ((S5:3/T7:1)PB23); also elsewhere on the board
D27_!XB2_PWR: IC2.19 ((S4:2/T5:0|0:4)PB10)
D28_CS_XB2: IC2.23 ((XIN/S2:2|4:2/T3:0|0:4)PA14); also elsewhere on the board
D29_INT_XB2: IC2.24 ((XOUT/S2:3|4:3/T3:1|0:5)PA15); also elsewhere on the board
D30_TX_XB2: IC2.15 ((S0:2|2:2/T1:0|0:2/AIN18)PA10)
D31_RX_XB2: IC2.16 ((S0:3|2:3/T1:1|0:3/AIN19)PA11)
GND: C1.1, C2.1, C3.1, C4.1, C6.1, C7.1, C8.1, C9.1, C10.1, C11.1, C12.1, C13.1, C14.2, C15.1, D2.C, D3.C, D5.3 (A), D6.A, IC2.5 (GND), IC2.18 (GND), IC2.35 (GND), IC2.42 (GND), IC2.TP (GND), IC6.1 (GND), J1.GND, J1.GND2 (GND), J16.2-GND (GND), R1.1, R46.2, R47.2, SW1.3 (S1), SW1.4 (S1), SW2.1, SW2.2 (P1); also elsewhere on the board
unnamed: C14.1, IC2.1 ((XIN32/S1:0/T2:0)PA00), Q1.2
unnamed: C15.2, IC2.2 ((XOUT32/S1:1/T2:1)PA01), Q1.1
unnamed: D2.A, R3.2
unnamed: D3.A, R4.2
unnamed: R6.2, SW2.3 (S1), SW2.4 (S1)
RST: C12.2, IC2.40 (!RESET), J16.3-RST (RST), R6.1, R7.2
SHLD: J1.S@1 (SHIELD), J1.S@2 (SHIELD), J1.S@3 (SHIELD), J1.S@4 (SHIELD), J1.S@5 (SHIELD), J1.S@6 (SHIELD), J1.S@7 (SHIELD), J1.S@8 (SHIELD), J1.S@9 (SHIELD), R1.2
SW: R2.2, SW1.1, SW1.2 (P1)
SWCLK: IC2.45 ((SWCLK/S1:2/T1:0)PA30), J16.4-SWDCLK (SWCLK), R5.2
SWDIO: IC2.46 ((SWDIO/S1:3/T1:1)PA31), J16.5-SWDIO (SWDIO)
USB_D_N: D5.1 (C1), IC2.33 ((USBM/S3:2|5:2/T5:0|1:2)PA24), J1.A7 (D-), J1.B7 (D-)
USB_D_P: D5.2 (C2), IC2.34 ((USBP/S3:3|5:3/T5:1|1:3)PA25), J1.A6 (D+), J1.B6 (D+)
VBUS: F1.1, J1.VBUS, J1.VBUS2 (VBUS)
VCCANA: C8.2, C10.2, C11.2, IC2.6 (VCCANA), L1.2
VCCCORE: C13.2, IC2.43 (VCCCORE)

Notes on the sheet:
Released under the CERN Open Hardware Lizenz 1.2 https://www.ohwr.org/projects/cernohl/wiki Designed by Watterott electronic for senseBox https://sensebox.de
USB
SAMD21
Power

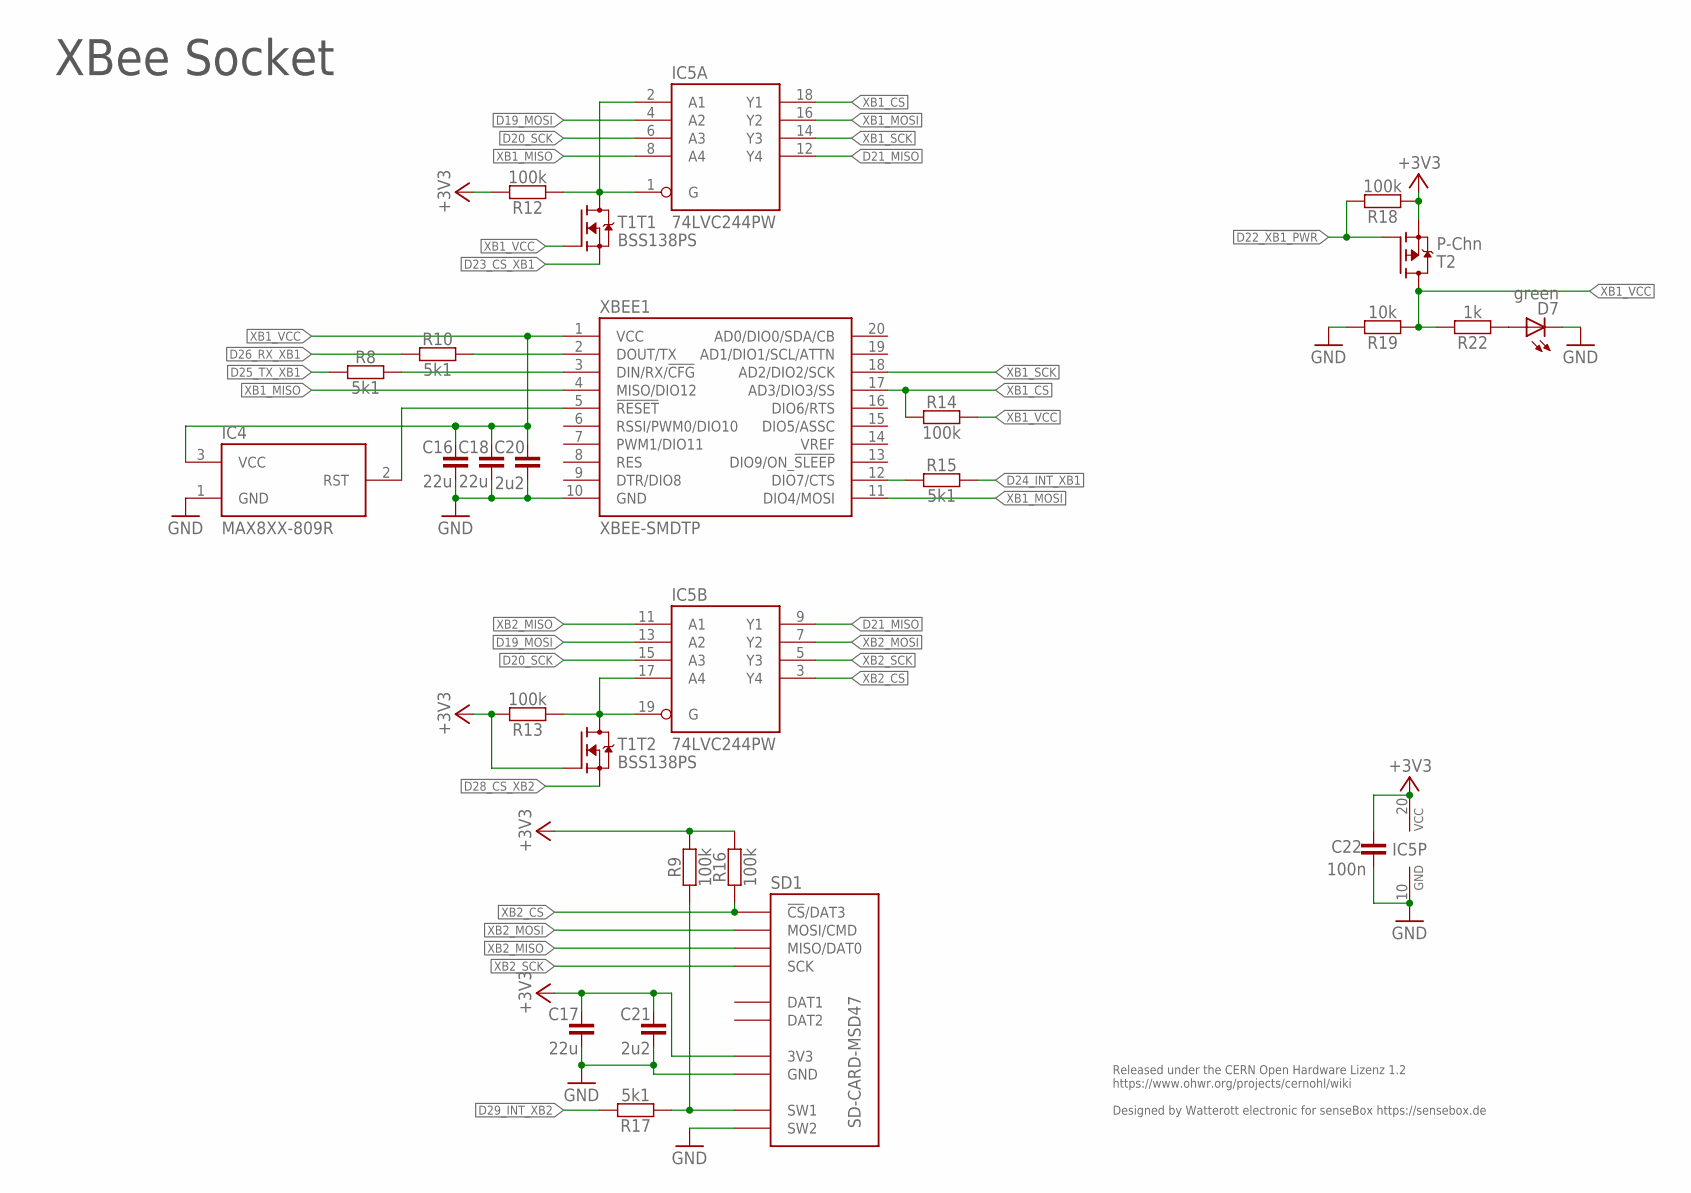
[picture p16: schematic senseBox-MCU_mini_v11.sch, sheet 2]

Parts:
C16, C17, C18: 22u; C0805
C20, C21: 2u2; C0402
C22: 100n; C0402
D7: green; C0603
IC4: MAX8XX-809R; SOT23
IC5: 74LVC244PW; TSSOP20
R8, R10, R15, R17: 5k1; C0402
R9, R12, R13, R14, R16, R18: 100k; C0402
R19: 10k; C0402
R22: 1k; C0402
SD1: SD-CARD-MSD47; SD_47309XXXX
T1: BSS138PS; SOT363
T2: P-Chn; SOT23
XBEE1: XBEE-SMDTP; XBEE_SMD_TP

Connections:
+3V3: C17.2, C21.2, C22.2, IC5.20 (VCC), R9.2, R12.2, R13.2, R16.2, R18.1, SD1.VCC (3V3), T1.5 (G), T2.2 (S); also elsewhere on the board
D19_MOSI: IC5.4 (A2), IC5.13 (A2); also elsewhere on the board
D20_SCK: IC5.6 (A3), IC5.15 (A3); also elsewhere on the board
D21_MISO: IC5.9 (Y1), IC5.12 (Y4); also elsewhere on the board
D22_!XB1_PWR: R18.2, T2.1 (G); also elsewhere on the board
D23_CS_XB1: T1.1 (S); also elsewhere on the board
D24_INT_XB1: R15.2; also elsewhere on the board
D25_TX_XB1: R8.1; also elsewhere on the board
D26_RX_XB1: R10.1; also elsewhere on the board
D28_CS_XB2: T1.4 (S); also elsewhere on the board
D29_INT_XB2: R17.2; also elsewhere on the board
GND: C16.1, C17.1, C18.1, C20.1, C21.1, C22.1, D7.C, IC4.1 (GND), IC5.10 (GND), R19.2, SD1.GND, SD1.GND@1 (GND), SD1.GND@2 (GND), SD1.SW2, XBEE1.10 (GND); also elsewhere on the board
MCU_CS_XBEE1: IC5.1 (G), IC5.2 (A1), R12.1, T1.6 (D)
MCU_CS_XBEE2: IC5.17 (A4), IC5.19 (G), R13.1, T1.3 (D)
unnamed: R9.1, R17.1, SD1.SW1
unnamed: D7.A, R22.1
RST_XB1: IC4.2 (RST), XBEE1.5 (!RESET!)
XB1_CS: IC5.18 (Y1), R14.1, XBEE1.17 (AD3/DIO3/SS)
XB1_MISO: IC5.8 (A4), XBEE1.4 (MISO/DIO12)
XB1_MOSI: IC5.16 (Y2), XBEE1.11 (DIO4/MOSI)
XB1_RX: R8.2, XBEE1.3 (DIN/RX/!CFG!)
XB1_SCK: IC5.14 (Y3), XBEE1.18 (AD2/DIO2/SCK)
XB1_TX: R10.2, XBEE1.2 (DOUT/TX)
XB1_VCC: C16.2, C18.2, C20.2, IC4.3 (VCC), R14.2, R19.1, R22.2, T1.2 (G), T2.3 (D), XBEE1.1 (VCC)
XB2_CS: IC5.3 (Y4), R16.1, SD1.CS (!CS!/DAT3)
XB2_MISO: IC5.11 (A1), SD1.MISO (MISO/DAT0)
XB2_MOSI: IC5.7 (Y2), SD1.MOSI (MOSI/CMD)
XB2_SCK: IC5.5 (Y3), SD1.SCK
XBEE1_CTS/IRQ: R15.1, XBEE1.12 (DIO7/CTS)

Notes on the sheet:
Released under the CERN Open Hardware Lizenz 1.2 https://www.ohwr.org/projects/cernohl/wiki Designed by Watterott electronic for senseBox https://sensebox.de
XBee Socket

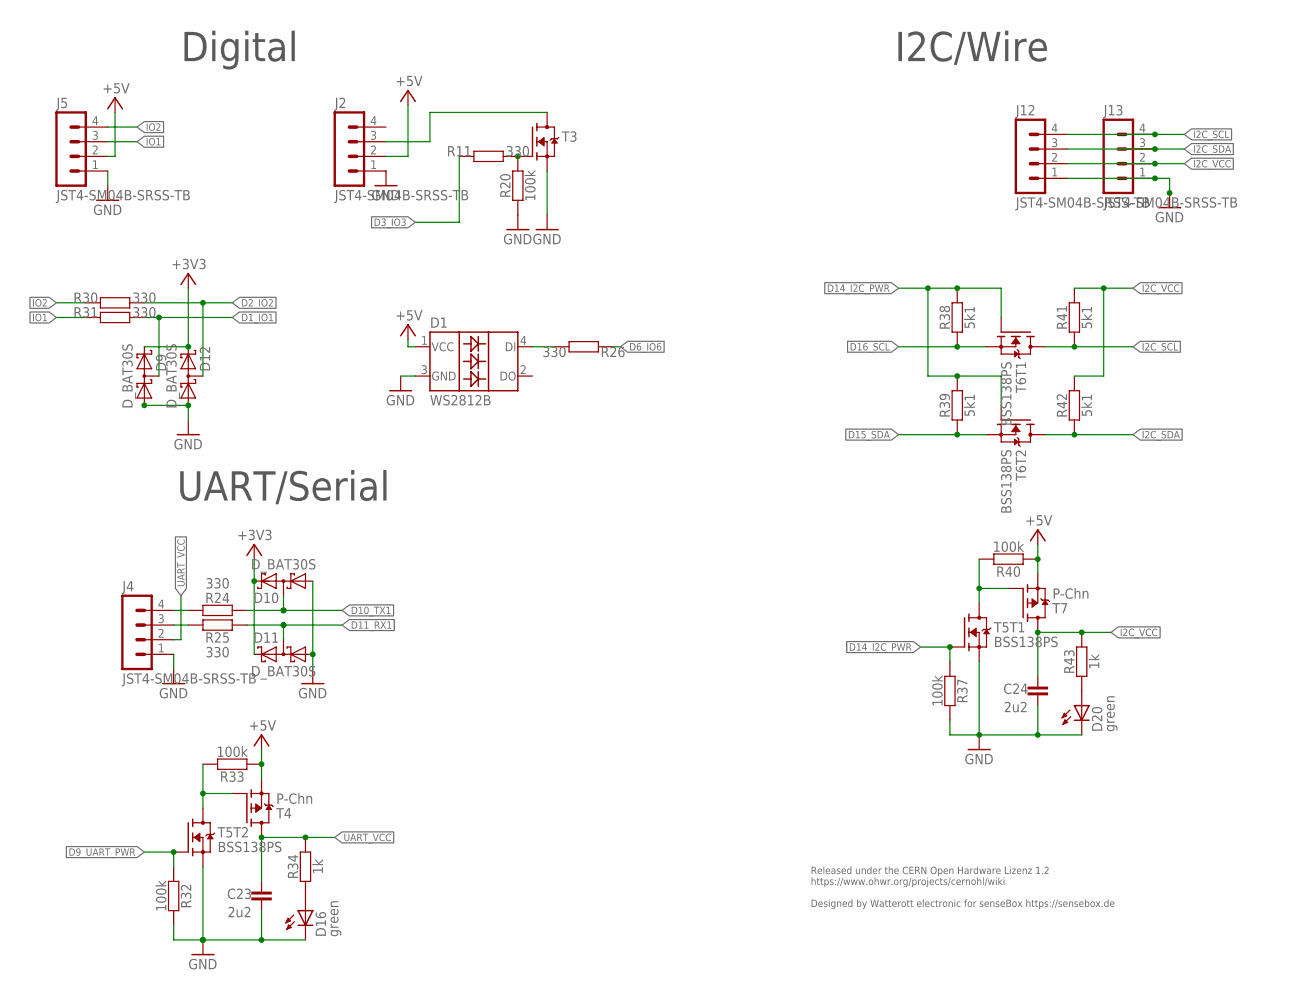
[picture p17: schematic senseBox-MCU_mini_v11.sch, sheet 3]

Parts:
C23, C24: 2u2; C0402
D1: WS2812B
D9, D10, D11, D12: D_BAT30S; SOT323
D16, D20: green; C0603
J2, J4, J5, J12, J13: JST4-SM04B-SRSS-TB; JST_SM04B-SRSS-TB
R11, R24, R25, R26, R30, R31: 330; C0402
R20, R32, R33, R37, R40: 100k; C0402
R34, R43: 1k; C0402
R38, R39, R41, R42: 5k1; C0402
T3: MOSFET-N-SOT23; SOT23
T4, T7: P-Chn; SOT23
T5, T6: BSS138PS; SOT363

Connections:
!I2C_POWER: R40.2, T5.6 (D), T7.1 (G)
!UART_POWER: R33.2, T4.1 (G), T5.3 (D)
+3V3: D9.2 (C), D10.2 (C), D11.2 (C), D12.2 (C); also elsewhere on the board
+5V: D1.1 (VCC), J2.2, J5.2, R33.1, R40.1, T4.2 (S), T7.2 (S); also elsewhere on the board
D1_IO1: D9.3 (CA), R31.1; also elsewhere on the board
D2_IO2: D12.3 (CA), R30.1; also elsewhere on the board
D3_IO3: R11.2; also elsewhere on the board
D6_IO6: R26.2; also elsewhere on the board
D9_UART_PWR: R32.1, T5.5 (G); also elsewhere on the board
D10_TX1: D10.3 (CA), R24.1; also elsewhere on the board
D11_RX1: D11.3 (CA), R25.1; also elsewhere on the board
D14_I2C_PWR: R37.1, R38.2, R39.2, T5.2 (G), T6.2 (G), T6.5 (G); also elsewhere on the board
D15_SDA: R39.1, T6.4 (S); also elsewhere on the board
D16_SCL: R38.1, T6.1 (S); also elsewhere on the board
GND: C23.1, C24.1, D1.3 (GND), D9.1 (A), D10.1 (A), D11.1 (A), D12.1 (A), D16.C, D20.C, J2.1, J4.1, J5.1, J12.1, J13.1, R20.1, R32.2, R37.2, T3.2 (S), T5.1 (S), T5.4 (S); also elsewhere on the board
I2C_SCL: J12.4, J13.4, R41.1, T6.6 (D)
I2C_SDA: J12.3, J13.3, R42.1, T6.3 (D)
I2C_VCC: C24.2, J12.2, J13.2, R41.2, R42.2, R43.2, T7.3 (D)
IO1: J5.3, R31.2
IO2: J5.4, R30.2
unnamed: D1.4 (DI), R26.1
unnamed: J2.3, T3.3 (D)
unnamed: D20.A, R43.1
unnamed: D16.A, R34.1
SW_FAN: R11.1, R20.2, T3.1 (G)
UART_RX1: J4.3, R25.2
UART_TX1: J4.4, R24.2
UART_VCC: C23.2, J4.2, R34.2, T4.3 (D)

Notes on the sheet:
Released under the CERN Open Hardware Lizenz 1.2 https://www.ohwr.org/projects/cernohl/wiki Designed by Watterott electronic for senseBox https://sensebox.de
Digital
I2C/Wire
UART/Serial

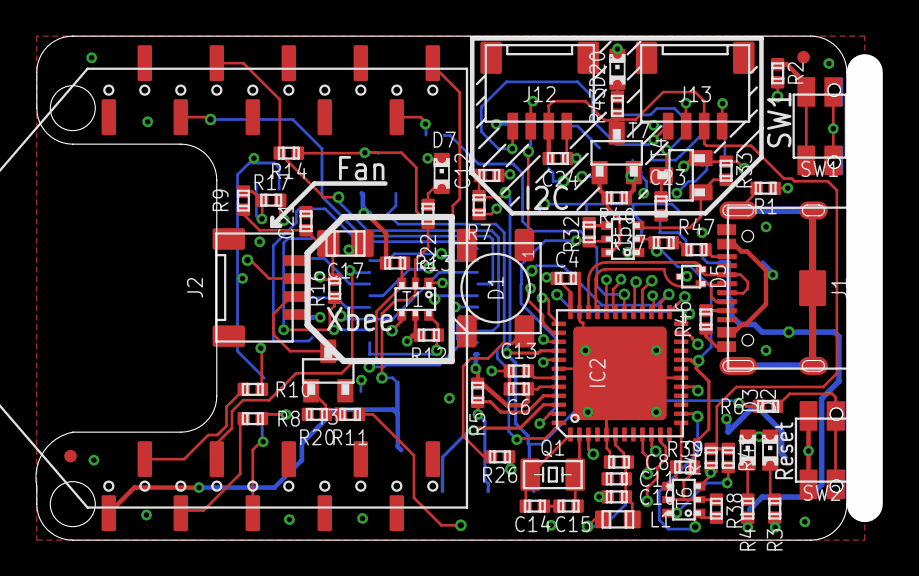
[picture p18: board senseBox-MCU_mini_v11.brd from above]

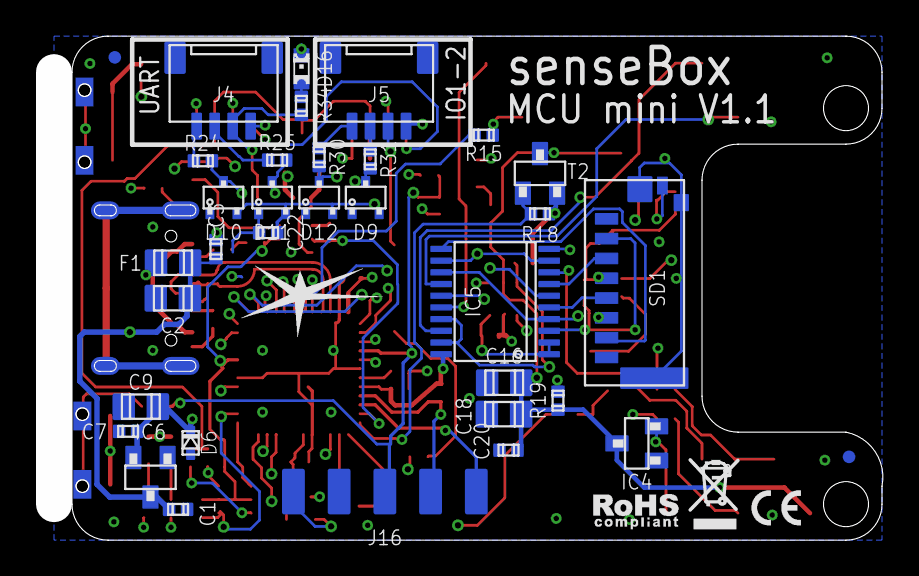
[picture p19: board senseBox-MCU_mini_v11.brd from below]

Board: 4 copper layers, 46.0 x 28.0 mm, 105 parts (38 on the bottom side), 75 nets.

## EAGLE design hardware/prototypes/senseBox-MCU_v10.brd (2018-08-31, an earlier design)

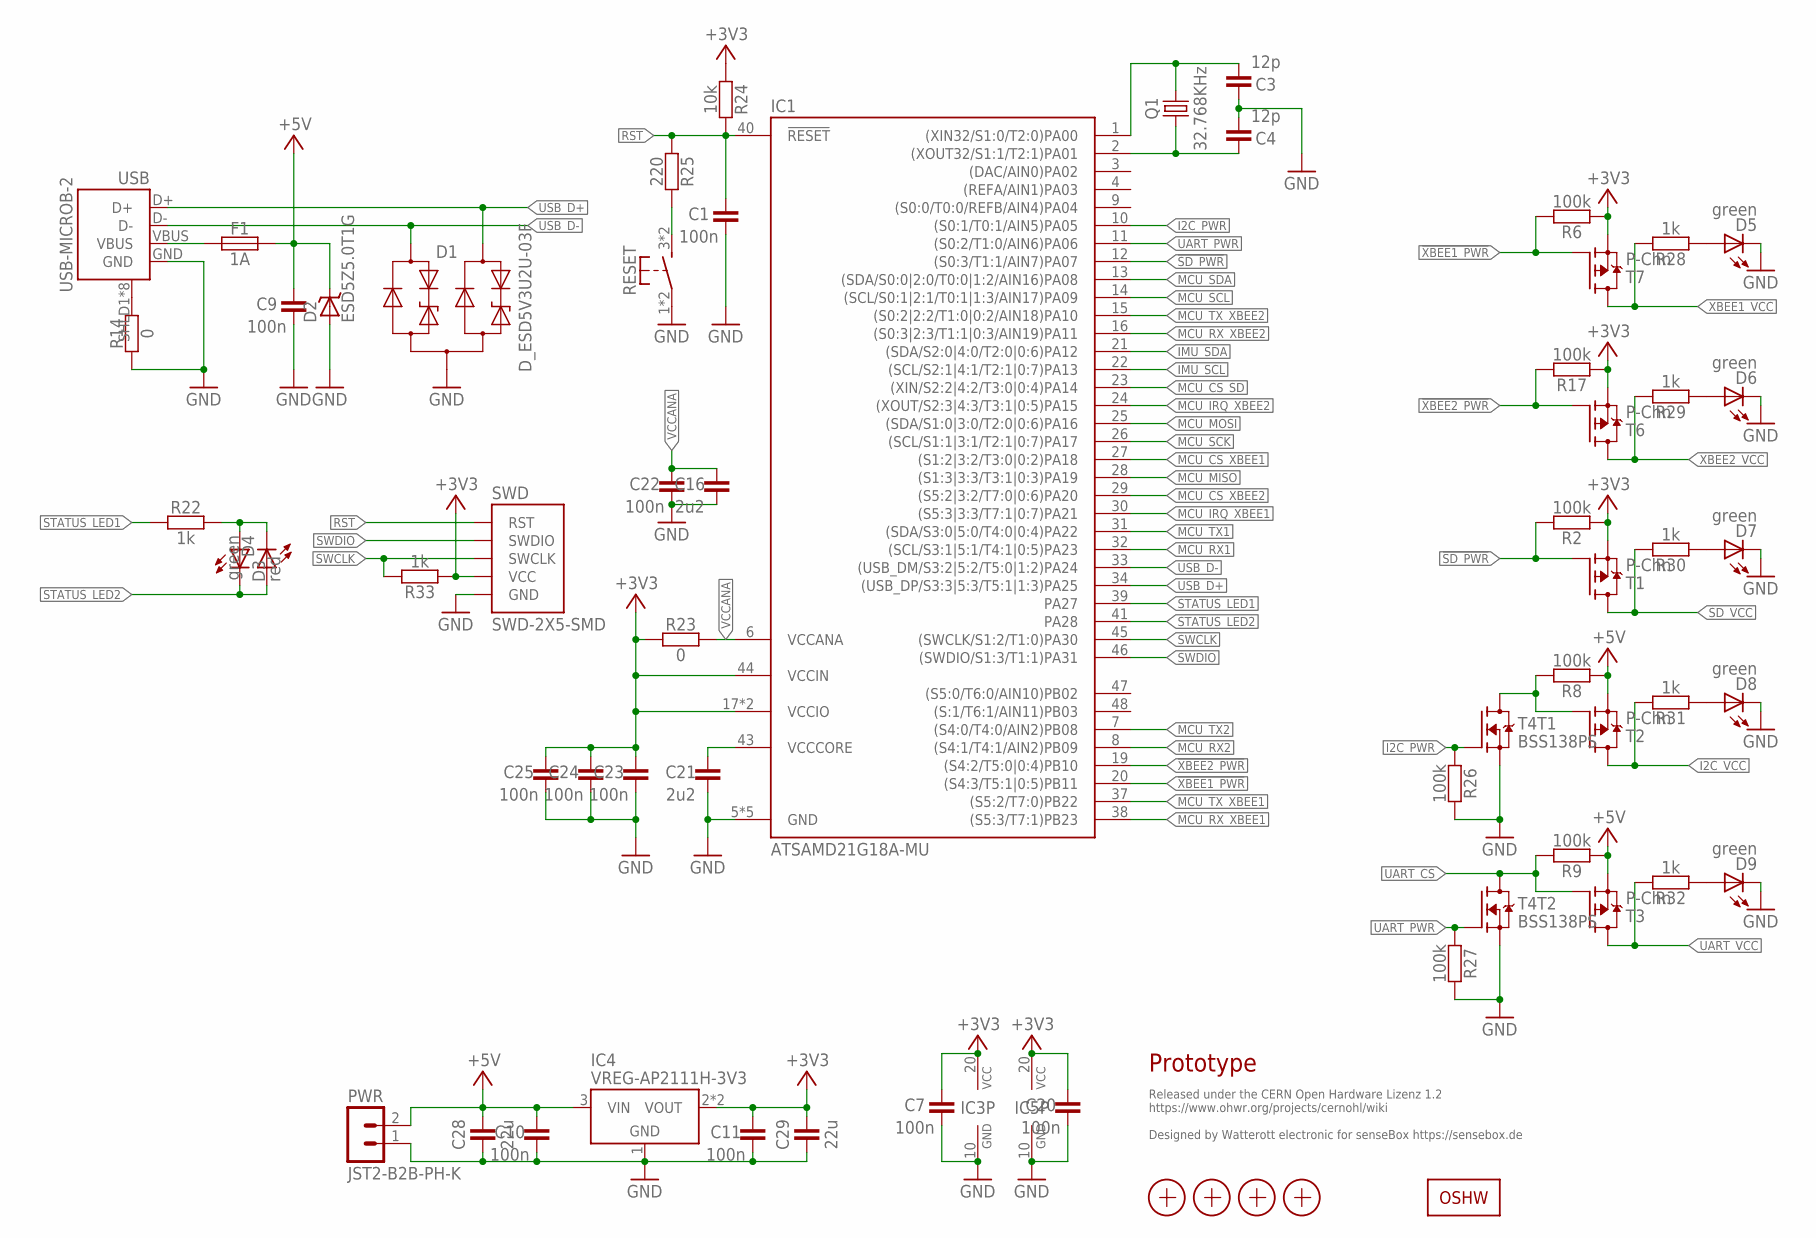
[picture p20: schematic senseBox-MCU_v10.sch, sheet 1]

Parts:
C1, C7, C9, C10, C11, C20, C22, C23, C24, C25: 100n; C0402
C3, C4: 12p; C0402
C16, C21: 2u2; C0402
C28, C29: 22u; C0805
D1: D_ESD5V3U2U-03F; SOT723
D2: ESD5Z5.0T1G; SOD523
D3: red; C0603
D4, D5, D6, D7, D8, D9: green; C0603
F1: 1A; C0805
IC1: ATSAMD21G18A-MU; QFN48-PAD
IC3, IC5: 74LVC244PW; TSSOP20
IC4: VREG-AP2111H-3V3; SOT223
LOGO2: OSHW_LOGOX0070; OSHW_6X70
PWR: JST2-B2B-PH-K; JST_B2B-PH-K
Q1: 32.768KHz; CRYSTAL_ZM315
R2, R6, R8, R9, R17, R26, R27: 100k; C0402
R14, R23: 0; C0402
R22, R28, R29, R30, R31, R32, R33: 1k; C0402
R24: 10k; C0402
R25: 220; C0402
RESET: SW-TACTILE-PTS840P; PTS840P
SWD: SWD-2X5-SMD; SWD-2X5_SMD
T1, T2, T3, T6, T7: P-Chn; SOT23
T4: BSS138PS; SOT363
USB: USB-MICROB-2; USB-MICROB-10118194
X1, X2, X3, X4: PASSER-07; PASSER_07MM

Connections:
!I2C_POWER: R8.2, T2.1 (G), T4.6 (D)
!SD_PWR: IC1.12 ((S0:3/T1:1/AIN7)PA07), R2.2, T1.1 (G)
!XBEE1_PWR: IC1.20 ((S4:3/T5:1|0:5)PB11), R6.2, T7.1 (G)
!XBEE2_PWR: IC1.19 ((S4:2/T5:0|0:4)PB10), R17.2, T6.1 (G)
+3V3: C7.2, C11.2, C20.2, C23.2, C24.2, C25.2, C29.2, IC1.17 (VCCIO), IC1.36 (VCCIO), IC1.44 (VCCIN), IC3.20 (VCC), IC4.2 (VOUT), IC4.4 (VOUT), IC5.20 (VCC), R2.1, R6.1, R17.1, R23.1, R24.1, R33.1, SWD.VCC, T1.2 (S), T6.2 (S), T7.2 (S); also elsewhere on the board
+5V: C9.2, C10.2, C28.2, D2.C, F1.2, IC4.3 (VIN), PWR.2, R8.1, R9.1, T2.2 (S), T3.2 (S)
GND: C1.1, C3.2, C4.1, C7.1, C9.1, C10.1, C11.1, C16.1, C20.1, C21.1, C22.1, C23.1, C24.1, C25.1, C28.1, C29.1, D1.3 (A), D2.A, D5.C, D6.C, D7.C, D8.C, D9.C, IC1.5 (GND), IC1.18 (GND), IC1.35 (GND), IC1.42 (GND), IC1.TP (GND), IC3.10 (GND), IC4.1 (GND), IC5.10 (GND), PWR.1, R14.1, R26.2, R27.2, RESET.1, RESET.2 (P1), SWD.GND@1 (GND), SWD.GND@2 (GND), SWD.GND@3 (GND), T4.1 (S), T4.4 (S), USB.GND; also elsewhere on the board
I2C_PWR: IC1.10 ((S0:1/T0:1/AIN5)PA05), R26.1, T4.2 (G)
I2C_VCC: R31.2, T2.3 (D); also elsewhere on the board
IMU_SCL: IC1.22 ((SCL/S2:1|4:1/T2:1|0:7)PA13); also elsewhere on the board
IMU_SDA: IC1.21 ((SDA/S2:0|4:0/T2:0|0:6)PA12); also elsewhere on the board
MCU_CS_SD: IC1.23 ((XIN/S2:2|4:2/T3:0|0:4)PA14); also elsewhere on the board
MCU_CS_XBEE1: IC1.27 ((S1:2|3:2/T3:0|0:2)PA18); also elsewhere on the board
MCU_CS_XBEE2: IC1.29 ((S5:2|3:2/T7:0|0:6)PA20); also elsewhere on the board
MCU_IRQ_XBEE1: IC1.30 ((S5:3|3:3/T7:1|0:7)PA21); also elsewhere on the board
MCU_IRQ_XBEE2: IC1.24 ((XOUT/S2:3|4:3/T3:1|0:5)PA15); also elsewhere on the board
MCU_MISO: IC1.28 ((S1:3|3:3/T3:1|0:3)PA19); also elsewhere on the board
MCU_MOSI: IC1.25 ((SDA/S1:0|3:0/T2:0|0:6)PA16); also elsewhere on the board
MCU_RX1: IC1.32 ((SCL/S3:1|5:1/T4:1|0:5)PA23); also elsewhere on the board
MCU_RX2: IC1.8 ((S4:1/T4:1/AIN2)PB09); also elsewhere on the board
MCU_RX_XBEE1: IC1.38 ((S5:3/T7:1)PB23); also elsewhere on the board
MCU_RX_XBEE2: IC1.16 ((S0:3|2:3/T1:1|0:3/AIN19)PA11); also elsewhere on the board
MCU_SCK: IC1.26 ((SCL/S1:1|3:1/T2:1|0:7)PA17); also elsewhere on the board
MCU_SCL: IC1.14 ((SCL/S0:1|2:1/T0:1|1:3/AIN17)PA09); also elsewhere on the board
MCU_SDA: IC1.13 ((SDA/S0:0|2:0/T0:0|1:2/AIN16)PA08); also elsewhere on the board
MCU_TX1: IC1.31 ((SDA/S3:0|5:0/T4:0|0:4)PA22); also elsewhere on the board
MCU_TX2: IC1.7 ((S4:0/T4:0/AIN2)PB08); also elsewhere on the board
MCU_TX_XBEE1: IC1.37 ((S5:2/T7:0)PB22); also elsewhere on the board
MCU_TX_XBEE2: IC1.15 ((S0:2|2:2/T1:0|0:2/AIN18)PA10); also elsewhere on the board
unnamed: C3.1, IC1.1 ((XIN32/S1:0/T2:0)PA00), Q1.2
unnamed: C4.2, IC1.2 ((XOUT32/S1:1/T2:1)PA01), Q1.1
unnamed: D5.A, R28.1
unnamed: D6.A, R29.1
unnamed: D7.A, R30.1
unnamed: D8.A, R31.1
unnamed: D9.A, R32.1
unnamed: D3.A, D4.C, R22.2
unnamed: R25.2, RESET.3 (S1), RESET.4 (S1)
RST: C1.2, IC1.40 (!RESET), R24.2, R25.1, SWD.RST
SD_VCC: R30.2, T1.3 (D); also elsewhere on the board
SHLD: R14.2, USB.SHLD1 (SHIELD), USB.SHLD2 (SHIELD), USB.SHLD3 (SHIELD), USB.SHLD4 (SHIELD), USB.SHLD5 (SHIELD), USB.SHLD6 (SHIELD), USB.SHLD7 (SHIELD), USB.SHLD8 (SHIELD)
STATUS_LED1: IC1.39 (PA27), R22.1
STATUS_LED2: D3.C, D4.A, IC1.41 (PA28)
SWCLK: IC1.45 ((SWCLK/S1:2/T1:0)PA30), R33.2, SWD.SWCLK
SWDIO: IC1.46 ((SWDIO/S1:3/T1:1)PA31), SWD.SWDIO
UART_CS: R9.2, T3.1 (G), T4.3 (D); also elsewhere on the board
UART_PWR: IC1.11 ((S0:2/T1:0/AIN6)PA06), R27.1, T4.5 (G)
UART_VCC: R32.2, T3.3 (D); also elsewhere on the board
USB_D+: D1.2 (C2), IC1.34 ((USB_DP/S3:3|5:3/T5:1|1:3)PA25), USB.D+
USB_D-: D1.1 (C1), IC1.33 ((USB_DM/S3:2|5:2/T5:0|1:2)PA24), USB.D-
VBUS: F1.1, USB.VBUS
VCCANA: C16.2, C22.2, IC1.6 (VCCANA), R23.2
VCCCORE: C21.2, IC1.43 (VCCCORE)
XBEE1_VCC: R28.2, T7.3 (D); also elsewhere on the board
XBEE2_VCC: R29.2, T6.3 (D); also elsewhere on the board

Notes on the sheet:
Released under the CERN Open Hardware Lizenz 1.2 https://www.ohwr.org/projects/cernohl/wiki Designed by Watterott electronic for senseBox https://sensebox.de
Prototype

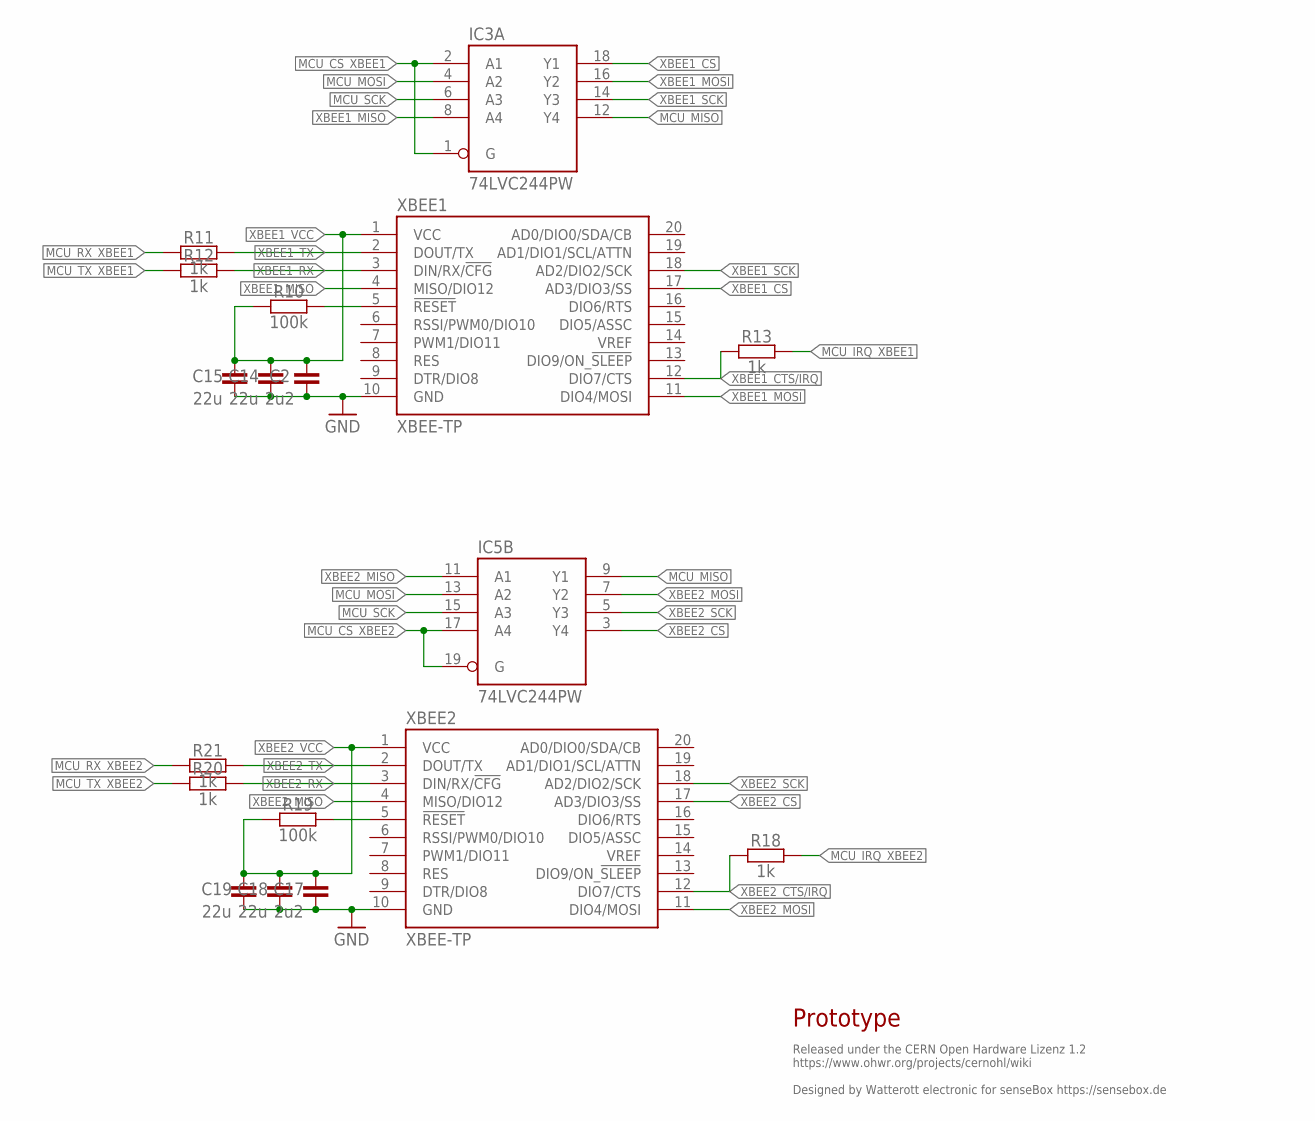
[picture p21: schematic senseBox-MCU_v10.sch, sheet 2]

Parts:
C2, C17: 2u2; C0402
C14, C15, C18, C19: 22u; C0805
IC3, IC5: 74LVC244PW; TSSOP20
R10, R19: 100k; C0402
R11, R12, R13, R18, R20, R21: 1k; C0402
XBEE1, XBEE2: XBEE-TP; XBEE_TP

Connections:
GND: C2.1, C14.1, C15.1, C17.1, C18.1, C19.1, XBEE1.10 (GND), XBEE2.10 (GND); also elsewhere on the board
MCU_CS_XBEE1: IC3.1 (G), IC3.2 (A1); also elsewhere on the board
MCU_CS_XBEE2: IC5.17 (A4), IC5.19 (G); also elsewhere on the board
MCU_IRQ_XBEE1: R13.2; also elsewhere on the board
MCU_IRQ_XBEE2: R18.2; also elsewhere on the board
MCU_MISO: IC3.12 (Y4), IC5.9 (Y1); also elsewhere on the board
MCU_MOSI: IC3.4 (A2), IC5.13 (A2); also elsewhere on the board
MCU_RX_XBEE1: R11.1; also elsewhere on the board
MCU_RX_XBEE2: R21.1; also elsewhere on the board
MCU_SCK: IC3.6 (A3), IC5.15 (A3); also elsewhere on the board
MCU_TX_XBEE1: R12.1; also elsewhere on the board
MCU_TX_XBEE2: R20.1; also elsewhere on the board
unnamed: R19.2, XBEE2.5 (!RESET!)
unnamed: R10.2, XBEE1.5 (!RESET!)
XBEE1_CS: IC3.18 (Y1), XBEE1.17 (AD3/DIO3/SS)
XBEE1_CTS/IRQ: R13.1, XBEE1.12 (DIO7/CTS)
XBEE1_MISO: IC3.8 (A4), XBEE1.4 (MISO/DIO12)
XBEE1_MOSI: IC3.16 (Y2), XBEE1.11 (DIO4/MOSI)
XBEE1_RX: R12.2, XBEE1.3 (DIN/RX/!CFG!)
XBEE1_SCK: IC3.14 (Y3), XBEE1.18 (AD2/DIO2/SCK)
XBEE1_TX: R11.2, XBEE1.2 (DOUT/TX)
XBEE1_VCC: C2.2, C14.2, C15.2, R10.1, XBEE1.1 (VCC); also elsewhere on the board
XBEE2_CS: IC5.3 (Y4), XBEE2.17 (AD3/DIO3/SS)
XBEE2_CTS/IRQ: R18.1, XBEE2.12 (DIO7/CTS)
XBEE2_MISO: IC5.11 (A1), XBEE2.4 (MISO/DIO12)
XBEE2_MOSI: IC5.7 (Y2), XBEE2.11 (DIO4/MOSI)
XBEE2_RX: R20.2, XBEE2.3 (DIN/RX/!CFG!)
XBEE2_SCK: IC5.5 (Y3), XBEE2.18 (AD2/DIO2/SCK)
XBEE2_TX: R21.2, XBEE2.2 (DOUT/TX)
XBEE2_VCC: C17.2, C18.2, C19.2, R19.1, XBEE2.1 (VCC); also elsewhere on the board

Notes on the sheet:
Released under the CERN Open Hardware Lizenz 1.2 https://www.ohwr.org/projects/cernohl/wiki Designed by Watterott electronic for senseBox https://sensebox.de
Prototype

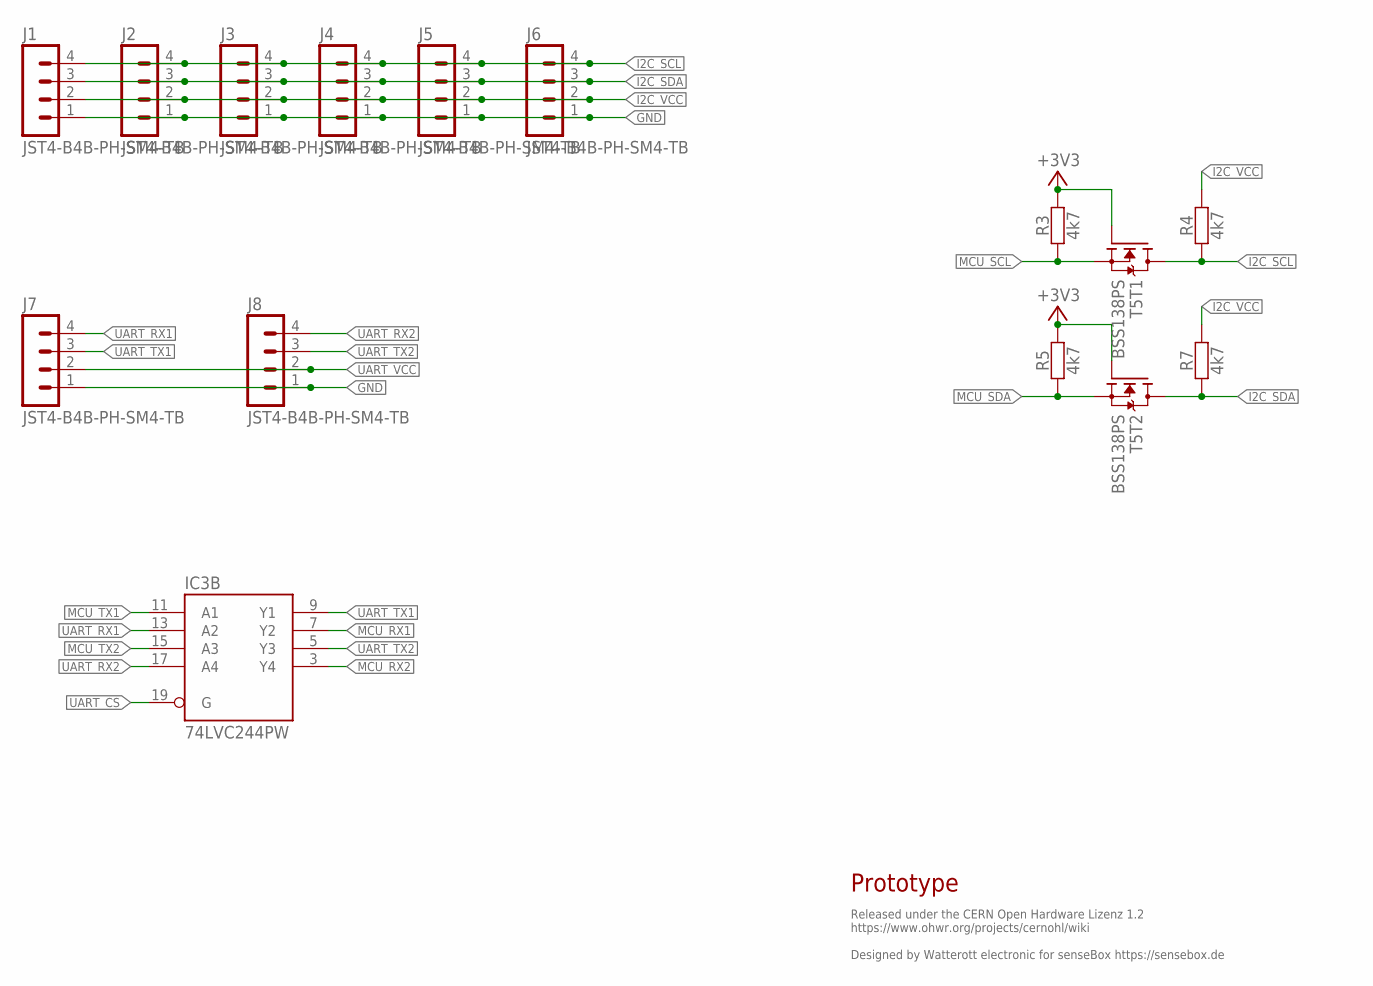
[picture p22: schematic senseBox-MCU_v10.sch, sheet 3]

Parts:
IC3: 74LVC244PW; TSSOP20
J1, J2, J3, J4, J5, J6, J7, J8: JST4-B4B-PH-SM4-TB; JST_B4B-PH-SM4-TB
R3, R4, R5, R7: 4k7; C0402
T5: BSS138PS; SOT363

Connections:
+3V3: R3.2, R5.2, T5.2 (G), T5.5 (G); also elsewhere on the board
GND: J1.1, J2.1, J3.1, J4.1, J5.1, J6.1, J7.1, J8.1; also elsewhere on the board
I2C_SCL: J1.4, J2.4, J3.4, J4.4, J5.4, J6.4, R4.1, T5.6 (D)
I2C_SDA: J1.3, J2.3, J3.3, J4.3, J5.3, J6.3, R7.1, T5.3 (D)
I2C_VCC: J1.2, J2.2, J3.2, J4.2, J5.2, J6.2, R4.2, R7.2; also elsewhere on the board
MCU_RX1: IC3.7 (Y2); also elsewhere on the board
MCU_RX2: IC3.3 (Y4); also elsewhere on the board
MCU_SCL: R3.1, T5.1 (S); also elsewhere on the board
MCU_SDA: R5.1, T5.4 (S); also elsewhere on the board
MCU_TX1: IC3.11 (A1); also elsewhere on the board
MCU_TX2: IC3.15 (A3); also elsewhere on the board
UART_CS: IC3.19 (G); also elsewhere on the board
UART_RX1: IC3.13 (A2), J7.4
UART_RX2: IC3.17 (A4), J8.4
UART_TX1: IC3.9 (Y1), J7.3
UART_TX2: IC3.5 (Y3), J8.3
UART_VCC: J7.2, J8.2; also elsewhere on the board

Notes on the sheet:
Released under the CERN Open Hardware Lizenz 1.2 https://www.ohwr.org/projects/cernohl/wiki Designed by Watterott electronic for senseBox https://sensebox.de
Prototype

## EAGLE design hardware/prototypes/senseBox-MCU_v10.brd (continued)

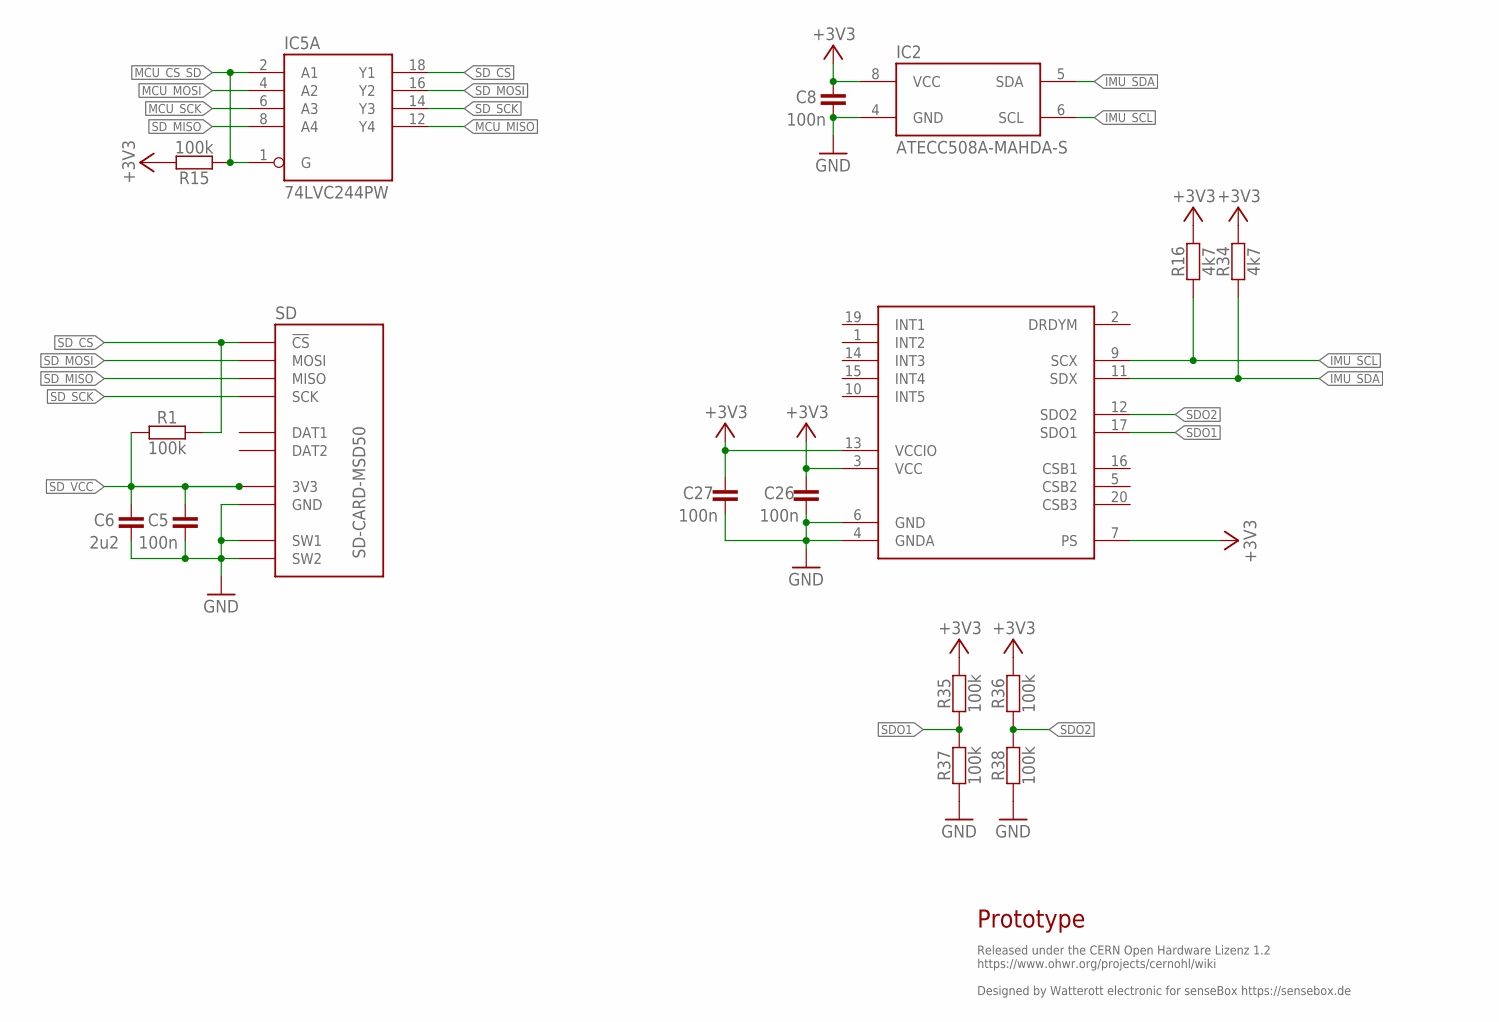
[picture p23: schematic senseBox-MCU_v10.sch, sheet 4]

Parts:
C5, C8, C26, C27: 100n; C0402
C6: 2u2; C0402
IC2: ATECC508A-MAHDA-S; UDFN8
IC5: 74LVC244PW; TSSOP20
R1, R15, R35, R36, R37, R38: 100k; C0402
R16, R34: 4k7; C0402
SD: SD-CARD-MSD50; SD_5031821853
U1: BMX055

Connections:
+3V3: C8.2, C26.2, C27.2, IC2.8 (VCC), R15.2, R16.2, R34.2, R35.2, R36.2, U1.3 (VCC), U1.7 (PS), U1.13 (VCCIO); also elsewhere on the board
GND: C5.1, C6.1, C8.1, C26.1, C27.1, IC2.4 (GND), R37.1, R38.1, SD.GND, SD.SW1, SD.SW2, U1.4 (GNDA), U1.6 (GND); also elsewhere on the board
IMU_SCL: IC2.6 (SCL), R16.1, U1.9 (SCX); also elsewhere on the board
IMU_SDA: IC2.5 (SDA), R34.1, U1.11 (SDX); also elsewhere on the board
MCU_CS_SD: IC5.1 (G), IC5.2 (A1), R15.1; also elsewhere on the board
MCU_MISO: IC5.12 (Y4); also elsewhere on the board
MCU_MOSI: IC5.4 (A2); also elsewhere on the board
MCU_SCK: IC5.6 (A3); also elsewhere on the board
SDO1: R35.1, R37.2, U1.17 (SDO1)
SDO2: R36.1, R38.2, U1.12 (SDO2)
SD_CS: IC5.18 (Y1), R1.2, SD.CS (!CS)
SD_MISO: IC5.8 (A4), SD.MISO
SD_MOSI: IC5.16 (Y2), SD.MOSI
SD_SCK: IC5.14 (Y3), SD.SCK
SD_VCC: C5.2, C6.2, R1.1, SD.VCC (3V3); also elsewhere on the board

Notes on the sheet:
Released under the CERN Open Hardware Lizenz 1.2 https://www.ohwr.org/projects/cernohl/wiki Designed by Watterott electronic for senseBox https://sensebox.de
Prototype

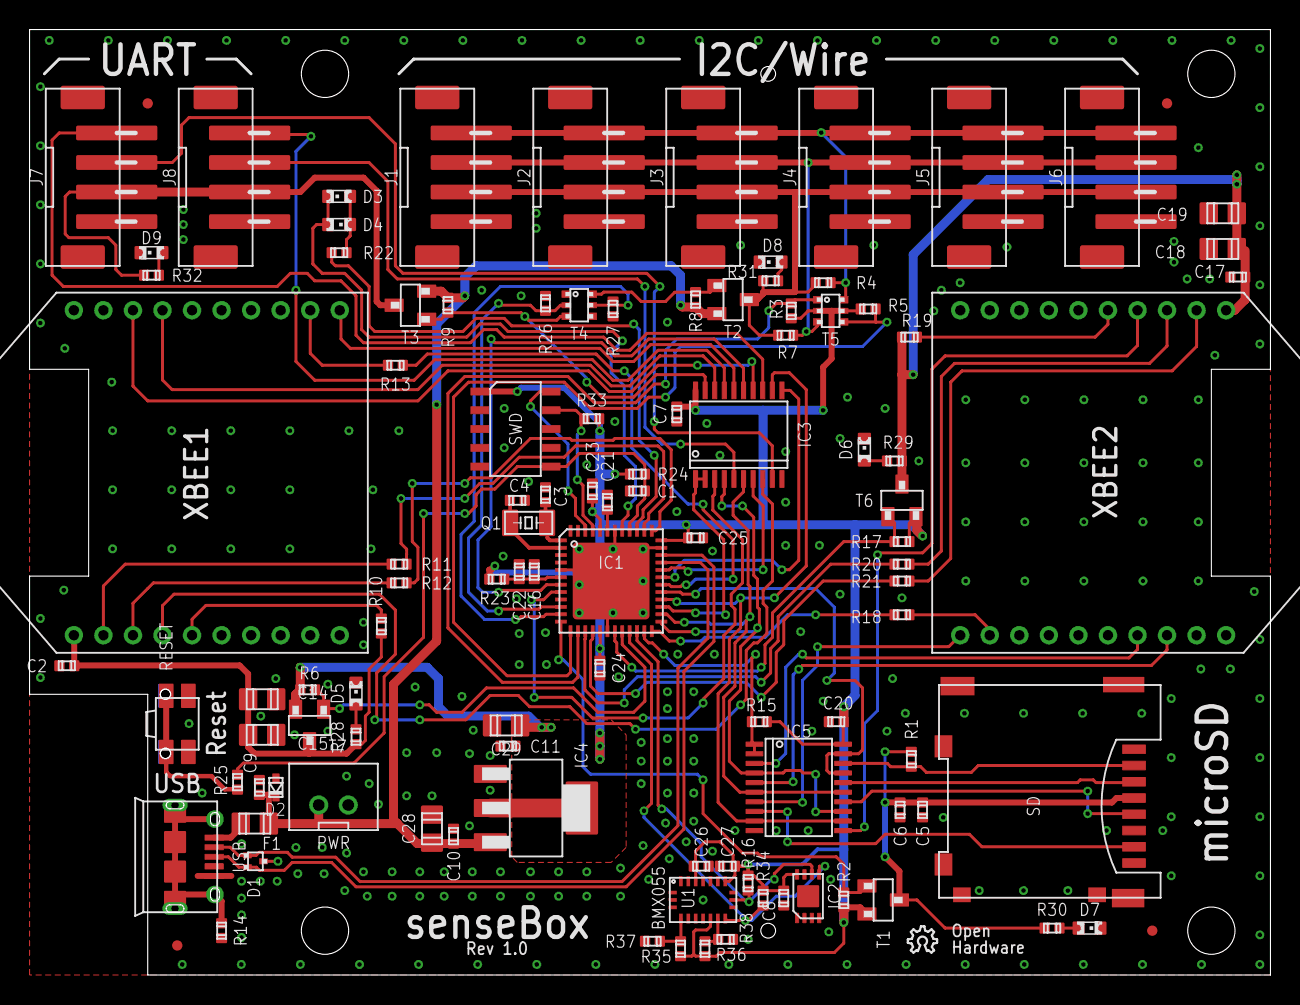
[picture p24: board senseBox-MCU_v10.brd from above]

Board: 2 copper layers, 84.0 x 64.0 mm, 109 parts (0 on the bottom side), 83 nets.

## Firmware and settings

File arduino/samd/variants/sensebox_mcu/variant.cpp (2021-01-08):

/*
  Copyright (c) 2014-2015 Arduino LLC.  All right reserved.

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
  You should have received a copy of the GNU Lesser General Public
  License along with this library; if not, write to the Free Software
  Foundation, Inc., 51 Franklin St, Fifth Floor, Boston, MA  02110-1301  USA
*/

#include "variant.h"
#include "Arduino.h"

const PinDescription g_APinDescription[] = {

/*
 +------------+------------------+--------+-----------------+--------+-----------------------+---------+---------+--------+--------+----------+----------+
 | Pin number | Board pin        |  PIN   | Notes           | Peri.A |     Peripheral B      | Perip.C | Perip.D | Peri.E | Peri.F | Periph.G | Periph.H |
 |            |                  |        |                 |   EIC  | ADC |  AC | PTC | DAC | SERCOMx | SERCOMx |  TCCx  |  TCCx  |    COM   | AC/GLCK  |
 |            |                  |        |                 |(EXTINT)|(AIN)|(AIN)|     |     | (x/PAD) | (x/PAD) | (x/WO) | (x/WO) |          |          |
 +------------+------------------+--------+-----------------+--------+-----+-----+-----+-----+---------+---------+--------+--------+----------+----------+
 | 00         | SW               |  PA20  |                 |  *04   |     |     | X08 |     |   5/02  |   3/02  |        |*TCC0/6 | I2S/SCK0 | GCLK_IO4 |
 | 01         | IO1 / REFB       |  PA04  |                 |   04   | *04 |  00 | Y02 |     |         |   0/00  |*TCC0/0 |        |          |          |
 | 02         | IO2              |  PA05  |                 |   05   | *05 |  01 | Y03 |     |         |   0/01  |*TCC0/1 |        |          |          |
 | 03         | IO3              |  PA06  |                 |   06   | *06 |  02 | Y04 |     |         |   0/02  | TCC1/0 |        |          |          |
 | 04         | IO4              |  PA07  |                 |   07   | *07 |  03 | Y05 |     |         |   0/03  | TCC1/1 |        | I2S/SD0  |          |
 | 05         | IO5 / REFA       |  PA03  |                 |   03   |  01 |     | Y01 |     |         |         |        |        |          |          |
 | 06         | IO6 / DAC0       |  PA02  |                 |   02   | *00 |     | Y00 | OUT |         |         |        |        |          |          |
 | 07         | LED red          |  PA27  |                 |   15   |     |     |     |     |         |         |        |        |          | GCLK_IO0 |
 | 08         | LED green        |  PA28  |                 |   08   |     |     |     |     |         |         |        |        |          | GCLK_IO0 |
 +------------+------------------+--------+-----------------+--------+-----+-----+-----+-----+---------+---------+--------+--------+----------+----------+
 */
  { PORTA, 20, PIO_DIGITAL, (PIN_ATTR_DIGITAL                                ), No_ADC_Channel, NOT_ON_PWM, NOT_ON_TIMER, EXTERNAL_INT_4    }, // SW
  { PORTA,  4, PIO_ANALOG,  (PIN_ATTR_DIGITAL|PIN_ATTR_PWM|PIN_ATTR_TIMER    ), ADC_Channel4,   PWM0_CH0,   TCC0_CH0,     EXTERNAL_INT_NONE }, // IO1
  { PORTA,  5, PIO_ANALOG,  (PIN_ATTR_DIGITAL|PIN_ATTR_PWM|PIN_ATTR_TIMER    ), ADC_Channel5,   PWM0_CH1,   TCC0_CH1,     EXTERNAL_INT_NONE }, // IO2
  { PORTA,  6, PIO_ANALOG,  (PIN_ATTR_DIGITAL|PIN_ATTR_PWM|PIN_ATTR_TIMER    ), ADC_Channel6,   PWM1_CH0,   TCC1_CH0,     EXTERNAL_INT_6    }, // IO3
  { PORTA,  7, PIO_ANALOG,  (PIN_ATTR_DIGITAL|PIN_ATTR_PWM|PIN_ATTR_TIMER    ), ADC_Channel7,   PWM1_CH1,   TCC1_CH0,     EXTERNAL_INT_7    }, // IO4
  { PORTA,  3, PIO_ANALOG,  (PIN_ATTR_DIGITAL                                ), ADC_Channel1,   NOT_ON_PWM, NOT_ON_TIMER, EXTERNAL_INT_3    }, // IO5
  { PORTA,  2, PIO_ANALOG,  (PIN_ATTR_DIGITAL|PIN_ATTR_ANALOG /*DAC*/        ), ADC_Channel0,   NOT_ON_PWM, NOT_ON_TIMER, EXTERNAL_INT_2    }, // IO6 / DAC
  { PORTA, 27, PIO_DIGITAL, (PIN_ATTR_DIGITAL                                ), No_ADC_Channel, NOT_ON_PWM, NOT_ON_TIMER, EXTERNAL_INT_NONE }, // LED red
  { PORTA, 28, PIO_DIGITAL, (PIN_ATTR_DIGITAL                                ), No_ADC_Channel, NOT_ON_PWM, NOT_ON_TIMER, EXTERNAL_INT_NONE }, // LED green
/*
 +------------+------------------+--------+-----------------+--------+-----------------------+---------+---------+--------+--------+----------+----------+
 | Pin number | Board pin        |  PIN   | Notes           | Peri.A |     Peripheral B      | Perip.C | Perip.D | Peri.E | Peri.F | Periph.G | Periph.H |
 |            |                  |        |                 |   EIC  | ADC |  AC | PTC | DAC | SERCOMx | SERCOMx |  TCCx  |  TCCx  |    COM   | AC/GLCK  |
 |            |                  |        |                 |(EXTINT)|(AIN)|(AIN)|     |     | (x/PAD) | (x/PAD) | (x/WO) | (x/WO) |          |          |
 +------------+------------------+--------+-----------------+--------+-----+-----+-----+-----+---------+---------+--------+--------+----------+----------+
 | 09         | PWR UART         |  PB02  |                 |  *02   | *10 |     | Y08 |     |         |   5/00  |        |        |          |          |
 | 10         | TX1              |  PA22  |                 |  *06   |     |     | X10 |     |   3/00  |   5/00  |* TC4/0 | TCC0/4 |          | GCLK_IO6 |
 | 11         | RX1              |  PA23  |                 |  *07   |     |     | X11 |     |   3/01  |   5/01  |* TC4/1 | TCC0/5 | USB/SOF  | GCLK_IO7 |
 | 12         | TX2              |  PB08  |                 |   08   |  02 |     | Y14 |     |         |   4/00  |  TC4/0 |        |          |          |
 | 13         | RX2              |  PB09  |                 |  *09   |  03 |     | Y15 |     |         |   4/01  |  TC4/1 |        |          |          |
 +------------+------------------+--------+-----------------+--------------------+-----+-----+---------+---------+--------+--------+----------+----------+
 | 14         | PWR I2C          |  PB11  |                 |  *11   |     |     |     |     |         |   4/03  |* TC5/1 | TCC0/5 | I2S/SCK1 | GCLK_IO5 |
 | 15         | SDA              |  PA08  |                 |   NMI  | *16 |     | X00 |     |  *0/00  |   2/00  | TCC0/0 | TCC1/2 | I2S/SD1  |          |
 | 16         | SCL              |  PA09  |                 |   09   | *17 |     | X01 |     |  *0/01  |   2/01  | TCC0/1 | TCC1/3 | I2S/MCK0 |          |
 +------------+------------------+--------+-----------------+--------------------+-----+-----+---------+---------+--------+--------+----------+----------+
 | 17         | SDA IMU          |  PA12  |                 |   12   |     |     |     |     |  *2/00  |   4/00  | TCC2/0 | TCC0/6 |          | AC/CMP0  |
 | 18         | SCL IMU          |  PA13  |                 |   13   |     |     |     |     |  *2/01  |   4/01  | TCC2/1 | TCC0/7 |          | AC/CMP1  |
 +------------+------------------+--------+-----------------+--------------------+-----+-----+---------+---------+--------+--------+----------+----------+
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

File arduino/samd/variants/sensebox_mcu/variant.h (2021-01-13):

/*
  Copyright (c) 2014-2015 Arduino LLC.  All right reserved.

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
  You should have received a copy of the GNU Lesser General Public
  License along with this library; if not, write to the Free Software
  Foundation, Inc., 51 Franklin St, Fifth Floor, Boston, MA  02110-1301  USA
*/

#pragma once

// The definitions here needs a SAMD core >=1.6.10
#define ARDUINO_SAMD_VARIANT_COMPLIANCE 10610

#include <WVariant.h>

// General definitions
// -------------------

// Frequency of the board main oscillator
#define VARIANT_MAINOSC (32768ul)
//#define CRYSTALLESS //do not use ext. crystal

// Master clock frequency
#define VARIANT_MCK     (48000000ul)

// Pins
// ----

// Number of pins defined in PinDescription array
#define PINS_COUNT           (34u) // 34
#define NUM_DIGITAL_PINS     (32u) // 32
#define NUM_ANALOG_INPUTS    (7u)  // 7
#define NUM_ANALOG_OUTPUTS   (1u)  // 1
#define analogInputToDigitalPin(p)  ((p < 7u) ? (p) : -1)

// Low-level pin register query macros
// -----------------------------------
#define digitalPinToPort(P)      (&(PORT->Group[g_APinDescription[P].ulPort]))
#define digitalPinToBitMask(P)   (1 << g_APinDescription[P].ulPin)
//#define analogInPinToBit(P)    ()
#define portOutputRegister(port) (&(port->OUT.reg))
#define portInputRegister(port)  (&(port->IN.reg))
#define portModeRegister(port)   (&(port->DIR.reg))
#define digitalPinHasPWM(P)      (g_APinDescription[P].ulPWMChannel != NOT_ON_PWM || g_APinDescription[P].ulTCChannel != NOT_ON_TIMER)

/*
 * digitalPinToTimer(..) is AVR-specific and is not defined for SAMD
 * architecture. If you need to check if a pin supports PWM you must
 * use digitalPinHasPWM(..).
 *
 * https://github.com/arduino/Arduino/issues/1833
 */
// #define digitalPinToTimer(P)

// senseBox MCU pins
// -----------------
#define PIN_UART_PWR  (9u)
#define PIN_UART_TX1  (10u)
#define PIN_UART_RX1  (11u)
#define PIN_UART_TX2  (12u)
#define PIN_UART_RX2  (13u)
#define PIN_I2C_PWR   (14u)
#define PIN_XB1_PWR   (22u)
#define PIN_XB1_CS    (23u)
#define PIN_XB1_INT   (24u)
#define PIN_XB1_TX    (25u)
#define PIN_XB1_RX    (26u)
#define PIN_XB2_PWR   (27u)
#define PIN_XB2_CS    (28u)
#define PIN_XB2_INT   (29u)
#define PIN_XB2_TX    (30u)
#define PIN_XB2_RX    (31u)
#define PIN_RED_LED   (7u)
#define PIN_GREEN_LED (8u)
#define PIN_SWITCH    (0u)
#define PIN_IO1       (1u)
#define PIN_IO2       (2u)
#define PIN_IO3       (3u)
#define PIN_IO4       (4u)
#define PIN_IO5       (5u)
#define PIN_IO6       (6u)

// LEDs
// ----
#define PIN_LED      (7u) // D7/PA27 (red)
#define PIN_LED2     (8u) // D8/PA28 (green)
#define LED_BUILTIN  PIN_LED
#define LED_BUILTIN2 PIN_LED2

// Analog pins
// -----------
#define PIN_A0   (1u)
#define PIN_A1   (1u)
#define PIN_A2   (2u)
#define PIN_A3   (3u)
#define PIN_A4   (4u)
#define PIN_A5   (5u)
#define PIN_A6   (6u)
#define PIN_DAC0 (6u)

static const uint8_t A0   = PIN_A0;
static const uint8_t A1   = PIN_A1;
static const uint8_t A2   = PIN_A2;
static const uint8_t A3   = PIN_A3;
static const uint8_t A4   = PIN_A4;
static const uint8_t A5   = PIN_A5;
static const uint8_t A6   = PIN_A6;
static const uint8_t DAC0 = PIN_DAC0;
#define ADC_RESOLUTION 12

// SPI Interfaces
// --------------
#define SPI_INTERFACES_COUNT 1

// SPI
#define PIN_SPI_MISO  (21u)
#define PIN_SPI_MOSI  (19u)
#define PIN_SPI_SCK   (20u)
#define PIN_SPI_SS    (23u) // CS XB1
#define PERIPH_SPI    sercom1 // sercom1 or sercom3
#define PAD_SPI_TX    SPI_PAD_0_SCK_1
#define PAD_SPI_RX    SERCOM_RX_PAD_3
static const uint8_t SS   = PIN_SPI_SS;   // SPI Slave SS not used. Set here only for reference.
static const uint8_t MOSI = PIN_SPI_MOSI;
static const uint8_t MISO = PIN_SPI_MISO;
static const uint8_t SCK  = PIN_SPI_SCK;

// Wire Interfaces
// ---------------
#define WIRE_INTERFACES_COUNT 2

// Wire
#define PIN_WIRE_SDA        (15u)
#define PIN_WIRE_SCL        (16u)
#define PERIPH_WIRE         sercom0 // sercom0 or sercom2
#define WIRE_IT_HANDLER     SERCOM0_Handler
static const uint8_t SDA = PIN_WIRE_SDA;
static const uint8_t SCL = PIN_WIRE_SCL;

#define PIN_WIRE1_SDA       (17u) // IMU
#define PIN_WIRE1_SCL       (18u) // IMU
#define PERIPH_WIRE1        sercom2 // sercom2 or sercom4
#define WIRE1_IT_HANDLER    SERCOM2_Handler
static const uint8_t SDA1 = PIN_WIRE1_SDA;
static const uint8_t SCL1 = PIN_WIRE1_SCL;

// USB
// ---
#define PIN_USB_DM          (32u)
#define PIN_USB_DP          (33u)
//#define PIN_USB_HOST_ENABLE (-1u)

// Needed for WINC1501B (WiFi101) library
// --------------------------------------
#define WINC1501_RESET_PIN   (-1) // no reset pin
#define WINC1501_CHIP_EN_PIN (-1) // no enable pin
#define WINC1501_INTN_PIN    (24) // 24 = INT XB1, 29 = INT XB2
#define WINC1501_SPI         SPI
#define WINC1501_SPI_CS_PIN  (23) // 23 = CS XB1, 28 = CS XB2
//#define NO_HW_CHIP_EN        (1) // No Chip Enable Pin

// Needed for SD library
// ---------------------
#define SDCARD_SS_PIN       (28u) // CS XB2

// Serial ports
// ------------
#ifdef __cplusplus
#include "SERCOM.h"
#include "Uart.h"

// Instances of SERCOM
extern SERCOM sercom0;
extern SERCOM sercom1;
extern SERCOM sercom2;
extern SERCOM sercom3;
extern SERCOM sercom4;
extern SERCOM sercom5;

// SERCOM3 oder SERCOM5 Serial1 UART RXTX1
extern Uart Serial1;
#define PIN_SERIAL1_RX (11u)
#define PIN_SERIAL1_TX (10u)
#define PAD_SERIAL1_TX (UART_TX_PAD_0)
#define PAD_SERIAL1_RX (SERCOM_RX_PAD_1)

// SERCOM4 Serial2 UART RXTX2
extern Uart Serial2;
#define PIN_SERIAL2_RX (13u)
#define PIN_SERIAL2_TX (12u)
#define PAD_SERIAL2_TX (UART_TX_PAD_0)
#define PAD_SERIAL2_RX (SERCOM_RX_PAD_1)

// SERCOM5 Serial3 XBEE1
extern Uart Serial3;
#define PIN_SERIAL3_RX (26u)
#define PIN_SERIAL3_TX (25u)
#define PAD_SERIAL3_TX (UART_TX_PAD_2)
#define PAD_SERIAL3_RX (SERCOM_RX_PAD_3)

// SERCOM0 oder SERCOM2 Serial4 XBEE2
/*
extern Uart Serial4;
#define PIN_SERIAL4_RX (31u)
#define PIN_SERIAL4_TX (30u)
#define PAD_SERIAL4_TX (UART_TX_PAD_2)
#define PAD_SERIAL4_RX (SERCOM_RX_PAD_3)
*/

#endif // __cplusplus

#ifdef __cplusplus
extern "C" {
#endif
unsigned int PINCOUNT_fn();
#ifdef __cplusplus
}
#endif
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

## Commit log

2017-12-23 added Arduino BSP
    [sensebox_mcu.cfg]
2017-12-24 updated pin defines
2018-01-20 power on all sockets
2018-03-02 updated driver
2018-03-08 renamed files
    [sensebox_mcu.cfg]
2018-03-18 updated bsp
    [sensebox_mcu.cfg]
2018-04-30 update status LED
2018-05-01 updated pin mapping
2018-05-01 updated analog pin map
2018-05-03 added layout and schematics
    [senseBox-MCU_v12.brd, senseBox-MCU_v12.sch]
2018-05-04 updated schematics
    [senseBox-MCU_v12.brd, senseBox-MCU_v12.sch]
2018-05-04 default power state changeable
2018-05-04 deactivate XB on power off
2018-06-26 added sensor mount
    [senseBox-Mount_v10.brd, senseBox-Mount_v10.dxf]
2018-07-28 enable pull-up on interrupt pins
2018-08-15 added Arduino BearSSL + ECCX08 lib
2018-08-16 added gerber files
2018-08-31 added prototypes
    [senseBox-MCU_v10.brd, senseBox-MCU_v10.sch, senseBox-MCU_v11.brd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]
2018-09-07 updated pin functions
2019-02-03 added rev 1.3
    [senseBox-MCU_v13.brd, senseBox-MCU_v13.sch]
2021-01-08 power on/off fix
2021-04-07 added rev 1.5
    [senseBox-MCU_v15.brd, senseBox-MCU_v15.sch]
2023-06-06 senseBox MCU mini
    added senseBox MCU mini
    [senseBox-MCU_mini_v11_V7.brd, senseBox-MCU_mini_v11_V7.sch]
2023-06-06 added Layout
    [senseBox-MCU_mini_v11.brd, senseBox-MCU_mini_v11.sch]
